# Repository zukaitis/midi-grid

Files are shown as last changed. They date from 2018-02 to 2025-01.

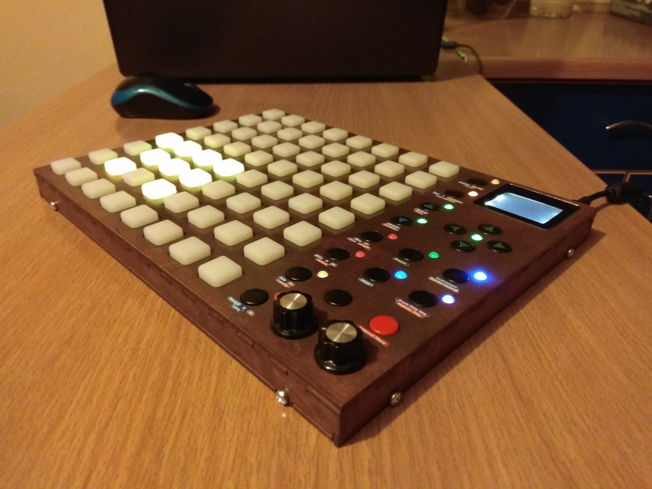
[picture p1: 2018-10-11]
Images/live_photo_8.jpg

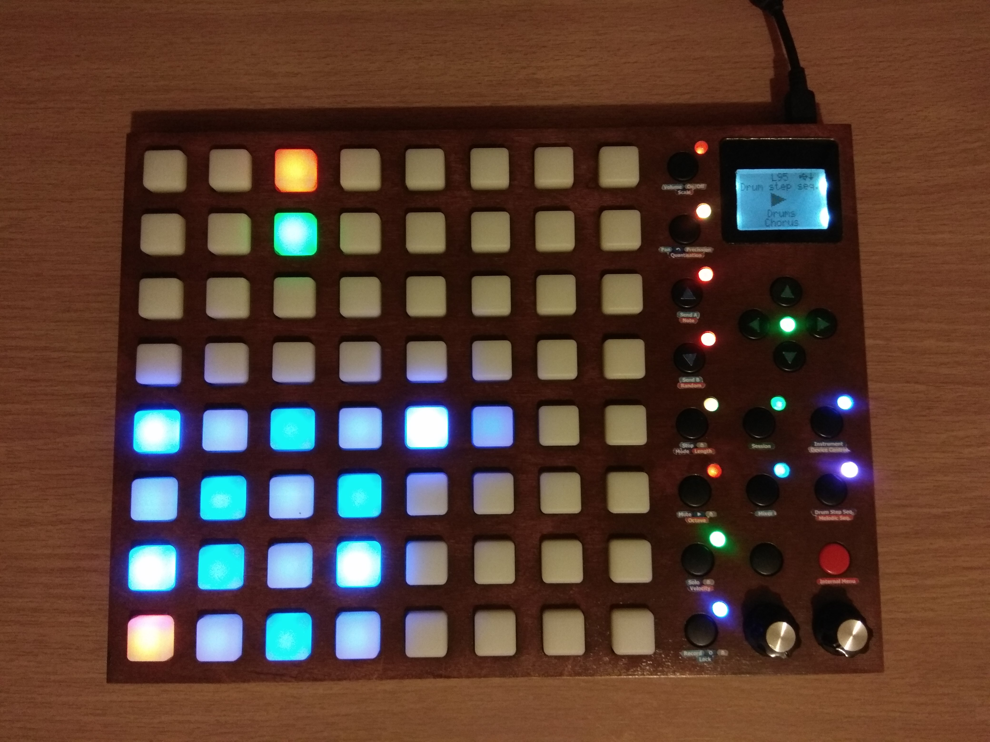
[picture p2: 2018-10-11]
Images/live_photo_12.jpg

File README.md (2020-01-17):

   

# midi-grid
DIY RGB MIDI grid controller

Video (https://youtu.be/mxI5Q21d1T0 "Demo video")

midi-grid is an open source MIDI controller, main part of which is 8x8 LED illuminated button grid.

Main features of the device:
- 8x8 RGB LED illuminated button matrix
- 17 additional MIDI control buttons, most of them paired with RGB LED indicator
- 1 internal menu button
- 2 rotary encoders, acting as MIDI controls
- Monochrome LCD display with adjustable backlight
- Physical MIDI input and output ports

Currently device is developed to work with [Ableton Live](https://www.ableton.com/en/live/),
specifically with modified [Launchpad95](http://motscousus.com/stuff/2011-07_Novation_Launchpad_Ableton_Live_Scripts/)
MIDI remote script - [Launchpad95g](https://github.com/zukaitis/Launchpad95g). Additional functionality, like stand-alone modes,
or compatibility with other DAWs may be implemented later.

More thorough information, regarding design and implementation, is available in [wiki of this project](https://github.com/zukaitis/midi-grid/wiki).

**This repository uses submodules -** [here's info how to fully clone it](https://stackoverflow.com/questions/3796927/how-to-git-clone-including-submodules)

## Thanks to
- [@mimuz](https://github.com/mimuz) - for sharing [STM32 USB MIDI library](https://github.com/mimuz/mimuz-tuch)
- [@pidcodes](https://github.com/pidcodes) - for providing USB VID/PID pair for this application
- [@hdavid](https://github.com/hdavid) - for making an amazing Ableton Live extension - [Launchpad95](https://github.com/hdavid/Launchpad95)
- [@michaelbecker](https://github.com/michaelbecker) - for making [FreeRTOS C++ wrappers](https://michaelbecker.github.io/freertos-addons)

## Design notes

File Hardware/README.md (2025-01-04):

# Bill of Materials

| Reference | Quantity | Part number | Description | Catalog link
| --- | --- | --- | --- | ---
| A1 | 1 | Nokia 5110 LCD | LCD module, ILI9341 controller, TFT LCD Display, 9-pin breakout PCB, SPI interface, 5V/3.3V | https://www.ebay.com/itm/84-48-LCD-Module-White-Backlight-Adapter-PCB-for-Nokia-5110-Arduino/400488314619
| C3, C2, C1, C6, C7, C8, C9, C11, C13, C17 | 10 |  | Capacitor MLCC, 100nF +/-10%, 6.3V, 0603, X5R | 
| C12, C10, C4, C5 | 4 |  | Capacitor MLCC, 2.2uF +/-10%, 6.3V, 0603, X5R | 
| C14, C15 | 2 |  | Capacitor MLCC, 27pF +/-10%, 6.3V, 0603, C0G | 
| C16, C18, C19, C21, C20 | 5 |  | Capacitor MLCC, 10uF +/-10%, 6.3V, 1206, X5R | 
| D1, D3, D5, D7, D9, D11, D13, D15, D17, D19, D21, D23, D25, D27, D29, D31, D33, D35, D37, D39, D41, D43, D45, D47, D49, D51, D53, D55, D57, D59, D61, D63, D65, D67, D69, D71, D73, D75, D77, D79, D81, D83, D85, D87, D89, D91, D93, D95, D97, D99, D101, D103, D105, D107, D109, D111, D113, D115, D117, D119, D121, D123, D125, D127, D129, D132, D136, D140, D142, D148, D150, D156, D134, D144, D152, D146, D154 | 77 |  | RGB LED, TH, d=5mm, p=1.27mm, common anode, diffused, pinout: RAGB | https://www.ebay.com/itm/100pcs-x-5mm-RGB-LED-Common-Cathode-Tri-Color-Emitting-Diodes-Diffused/291498456335
| D2, D4, D6, D8, D10, D12, D14, D16, D18, D20, D22, D24, D26, D28, D30, D32, D34, D36, D38, D40, D42, D44, D46, D48, D50, D52, D54, D56, D58, D60, D62, D64, D66, D68, D70, D72, D74, D76, D78, D80, D82, D84, D86, D88, D90, D92, D94, D96, D98, D100, D102, D104, D106, D108, D110, D112, D114, D116, D118, D120, D122, D124, D126, D128, D130, D133, D137, D141, D143, D149, D151, D157, D131, D135, D138, D139, D145, D153, D147, D155, D158 | 81 | LL4148-GS08 | 100V 0.3A standard switching diode, MiniMELF | https://www.tme.eu/en/details/ll4148-gs08/smd-universal-diodes/vishay/
| F1 | 1 | 1206L050YR | Polyfuse, 6V, 500mA, 1206 | https://eu.mouser.com/productdetail/?qs=PWhpLWeW8wckT8hV5jLiAA%3D%3D
| J1 | 1 | 105017-0001 | Connector, Micro USB | https://www.lemona.lt/?page=item&i_id=216110
| J2, J3 | 2 | FC68133 | 3-pin audio jack receptable (stereo/TRS connector) with 2 switching contacts | http://lt.farnell.com/cliff-electronic-components/fc68133/stereo-jack-3-5mm-5pos-pcb/dp/2518190
| J4 | 1 | 22-27-2041 | Generic connector, single row, 01x04 | 
| Q2, Q1, Q4, Q3, Q6, Q5, Q8, Q7, Q10, Q9, Q12, Q11, Q14, Q13, Q16, Q15, Q18, Q17, Q20, Q19 | 20 | BSH205G2 | MOSFET, P Channel, -2 A, -20 V, SOT-23 | http://uk.farnell.com/nexperia/bsh205g2/mosfet-p-ch-20v-2a-to236ab/dp/2498570
| Q28, Q27, Q26, Q25, Q32, Q31, Q30, Q29, Q24, Q23, Q22, Q21, Q33, Q34 | 14 | NX7002AK | MOSFET, N-Channel, 190 mA, 60 V, SOT-23 | http://uk.farnell.com/nexperia/nx7002ak/mosfet-single-n-ch-60v-0-19a-sot23/dp/2191746
| R21, R22, R23, R24, R64 | 5 |  | Resistor, 1K +/-5%, 0603 | 
| R28, R27, R26, R25 | 4 |  | Resistor, 249R +/-1%, 1206 | 
| R36, R35, R34, R33 | 4 |  | Resistor, 294R +/-1%, 1206 | 
| R44, R43, R42, R41 | 4 |  | Resistor, 51R +/-1%, 1206 | 
| R40, R39, R38, R37, R48, R47, R46, R45, R32, R31, R30, R29, R1, R2, R3, R4, R5, R6, R7, R8, R9, R10, R11, R12, R13, R14, R15, R16, R17, R18, R19, R20, R52, R51, R50, R49, R53, R54, R55, R59, R56, R63 | 42 |  | Resistor, 10K +/-5% 0603 | 
| R57, R58, R61, R60, R62 | 5 |  | Resistor, 220R +/-5%, 0603 | 
| R65 | 1 |  | Resistor, 1.6K +/-5%, 0603 | 
| SW1, SW2, SW3, SW4 | 4 |  | 4 x 4 silicone push button matrix, button size: 15mm x 15mm, matrix size 100mm x 100mm | http://www.better-silicone.com/Translucent-Silicone-Rubber-Button-Pad-4x4-Keyboard-pd847135.html
| SW5, SW6, SW7, SW8, SW9, SW10, SW11, SW12, SW13, SW14, SW15, SW16, SW17, SW18, SW19, SW20, SW23, SW24 | 18 |  | Tactile switch with stem for cap, 12mm x 12mm, h=7.3mm | https://www.ebay.com/itm/25PCS-12x12x7-3mm-Tact-Tactile-Push-Button-Momentary-SMD-PCB-Switch-with-Cap/382202288162
|  | 17 |  | Button cap, round, d=12mm, black | 
|  | 1 |  | Button cap, round, d=12mm, red | 
| SW21, SW22 | 2 |  | Tactile switch, 6mm x 6mm, h=4.3mm | 
| SW25, SW26 | 2 | EC12E24204A9 | Rotary encoder, incremental, 24 pulses/revolution | 
| U1 | 1 | STM32F413RHT6 | Microcontroller, ARM Cortex-M4, LQFP64, Flash: 1536KB Ram: 320KB,100MHz Voltage: 1.7..3.6V IO-pins: 50 | 
| U4, U3, U2 | 3 | SN74HC138PW | Decoder 3 to 8 (active low outputs), TSSOP-16 | http://uk.farnell.com/texas-instruments/sn74hc138pw/ic-decoder-demux-smd/dp/9591095
| U5 | 1 | USBUF02W6 | 2-line EMI filter and ESD protection with R pull-up, for USB interfaces, SOT-363 | http://uk.farnell.com/stmicroelectronics/usbuf02w6/filter-low-pass-1ghz-sot-323-6/dp/2341659
| U6 | 1 | VO617A | Optocoupler, SO-4 | https://eu.mouser.com/ProductDetail/Vishay-Semiconductors/VO617A-8X017T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
| U7 | 1 | LD1117STR | 800mA Low-Dropout Linear Regulator, adjustable output, SOT-223 | http://uk.farnell.com/stmicroelectronics/ld1117str/ic-v-reg-adj-1-25-15v-smd-1117/dp/1202824
| Y1 | 1 | ABM3B-8.000MHZ-B2-T | Crystal 8.0MHz 18pf 20ppm -20C +70C | https://eu.mouser.com/ProductDetail/?qs=NE97hfUNX0Ef9OqIOqO2cA%3D%3D
|  | 71 |  | Standoff, M2 * 5mm | https://www.ebay.com/itm/KNURLED-BRASS-SPACER-FEMALE-FEMALE-SCREW-PC-MOTHERBOARD-STANDOFF-M2-X-3MM-25MM-/122039617381
|  | 64 |  | Phillips screw, round head, M2 * 6mm | https://www.ebay.com/itm/M2-A2-304-Stainless-Steel-Phillips-Round-Head-Pan-Head-Screws-Bolts-M2-3-M2-60-/122691038427
|  | 23 |  | Phillips screw, flat head, M2 * 5mm | https://www.ebay.com/itm/M2-A2-304-Stainless-Steel-Phillips-Flat-Head-Screws-Bolts-M2-3mm-M2-60mm-/122689688965

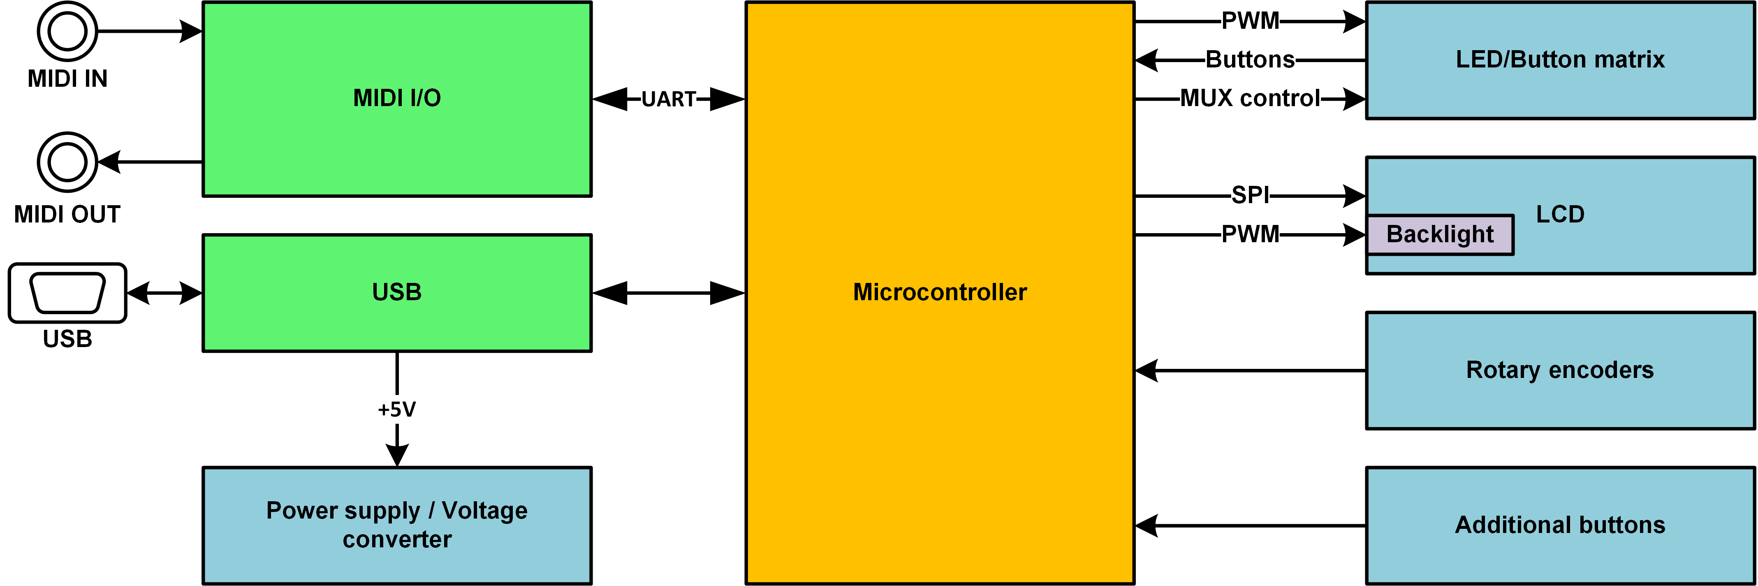
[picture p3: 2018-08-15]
Images/hardware_block_diagram.png

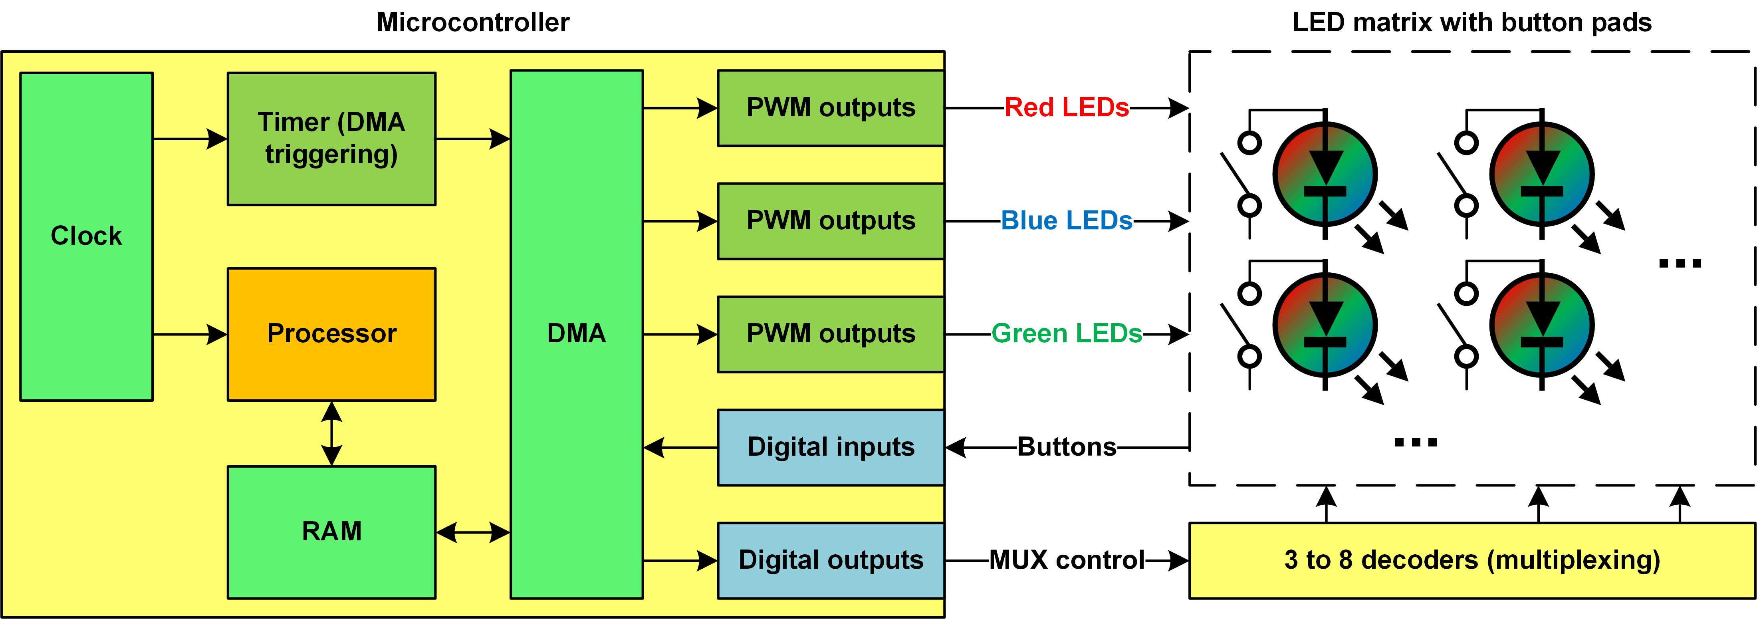
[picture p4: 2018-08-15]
Images/matrix_control_diagram.png

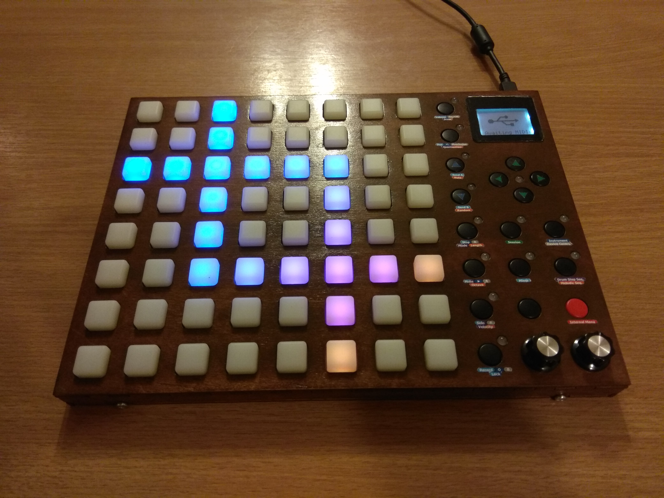
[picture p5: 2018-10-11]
Images/live_photo_1.jpg

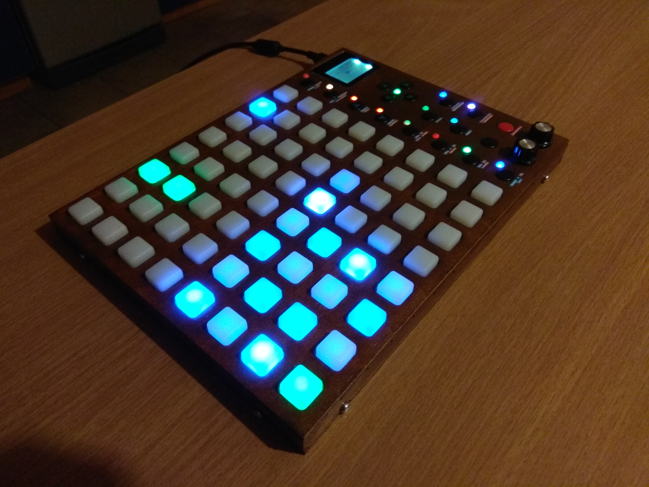
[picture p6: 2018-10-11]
Images/live_photo_4.jpg

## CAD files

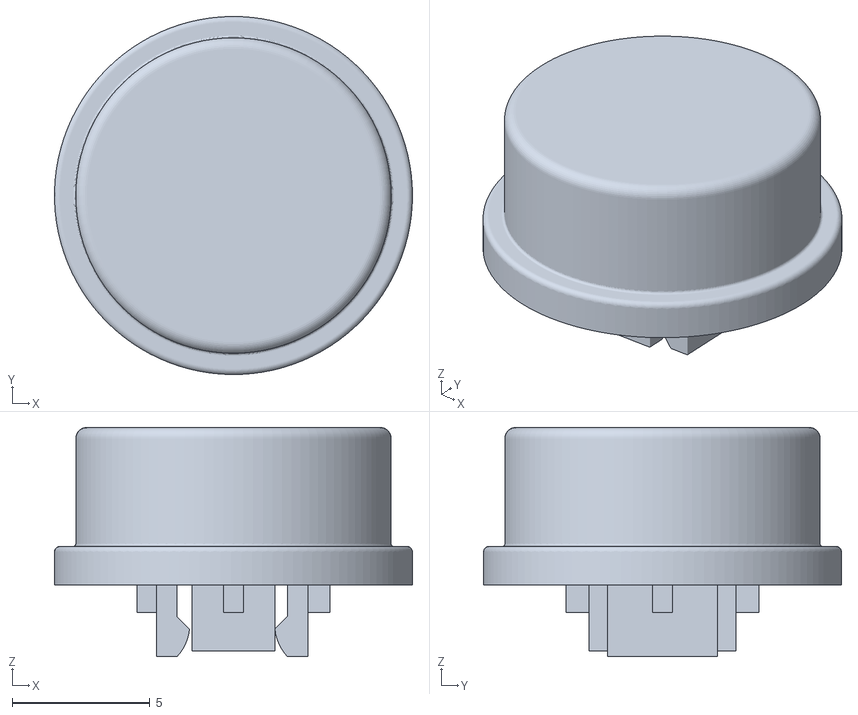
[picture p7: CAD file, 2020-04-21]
Case/models/adafruit_round_button_cap_1009.stl
13.0 x 13.0 x 8.32

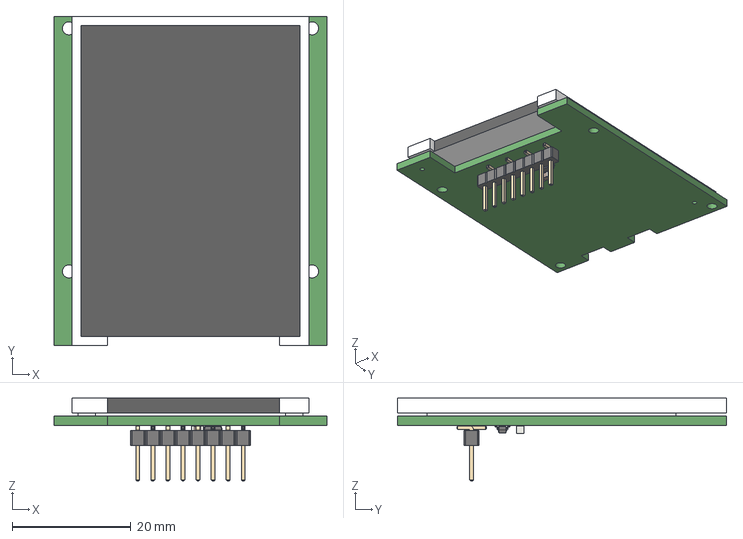
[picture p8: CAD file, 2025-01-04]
Hardware/lcd_board/lcd_board.step
46.0 x 55.5 x 14.0 mm

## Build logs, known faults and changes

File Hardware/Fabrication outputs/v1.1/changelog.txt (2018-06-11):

v1.1 - not yet fabricated
Changes:
- switched microcontroller pins LCD_DC and LCD_CS, so that hardware chip select of microcontroller could be used
- connected LCD_LIGHT output to PB5 GPIO pin (used to be TP3)

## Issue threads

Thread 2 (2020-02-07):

Need help for pcb

4dvn, 2020-02-07:
Can you upload the gerber file, i need the instruction to compile the source, thank you!

zukaitis, 2020-02-07:
I uploaded Gerber files for newest version into Hardware/Fabrication outputs/v1.1 . Although, be aware, that these files haven't yet been used in production, so make sure to review them with Gerber viewer of your choice

Closed 2020-02-07.

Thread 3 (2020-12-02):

Need help to custom it

4dvn, 2020-12-02:
I have a 16 buttons midi from avr project and i wanna switch it to stm32, can you give me some example code of it with rgb?

zukaitis, 2020-12-02:
Hey, all the hardware configuration (GPIO, PWM, DMA) is set up in [GridDriver.cpp](https://github.com/zukaitis/midi-grid/blob/master/Firmware/src/hardware/grid/GridDriver.cpp) file. Since you only need 16 buttons, you could get away with using as little as 3 PWM GPIO outputs (instead of 12 used in my circuit), but that depends on the way you want to connect them, check the [schematics](https://github.com/zukaitis/midi-grid/blob/master/Hardware/midi_grid.pdf) for reference. Hope that helps, have fun with your project!

Closed 2020-12-09.

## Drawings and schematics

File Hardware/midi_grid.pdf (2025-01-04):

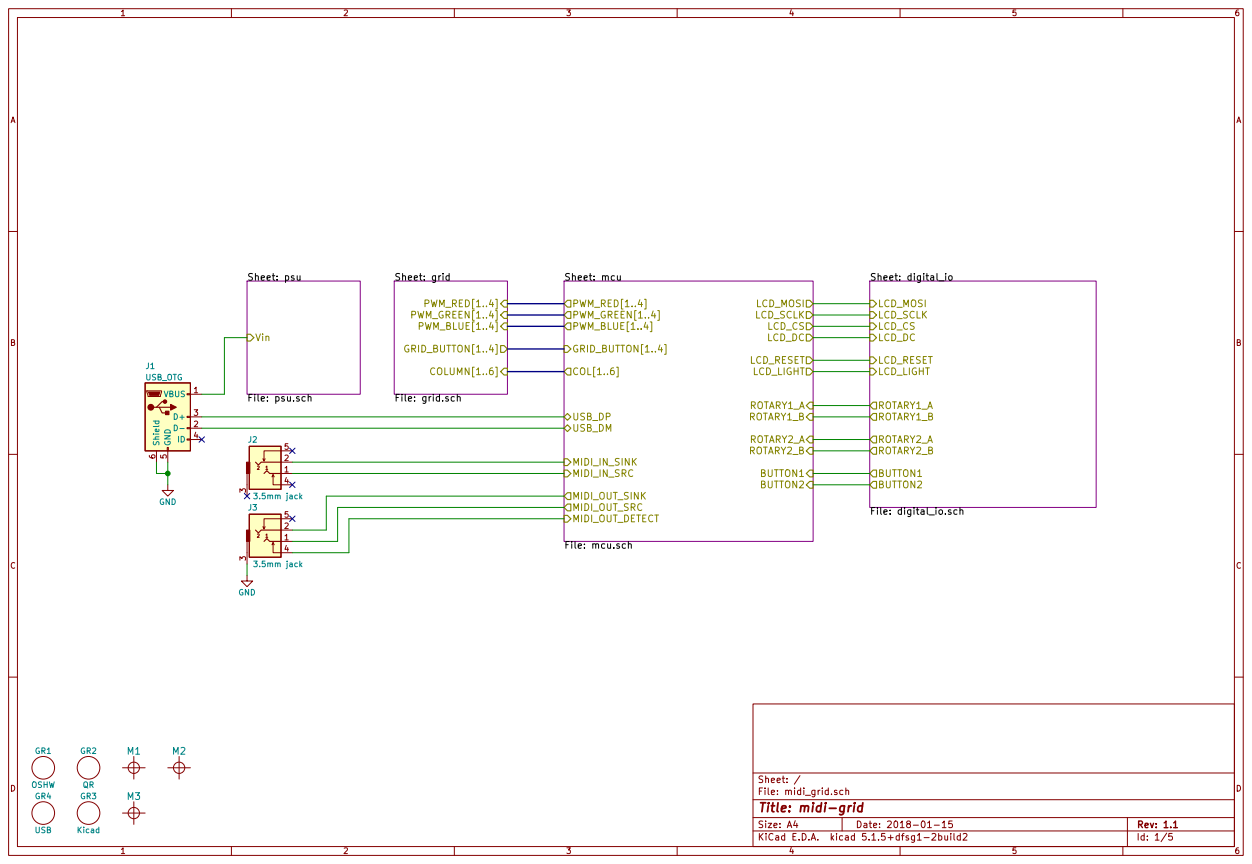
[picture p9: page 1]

Sheet: mcu File: mcu.sch PWM_RED[1..4]

File: midi_grid.sch Sheet: /
Id: 1/5 Title: midi-grid

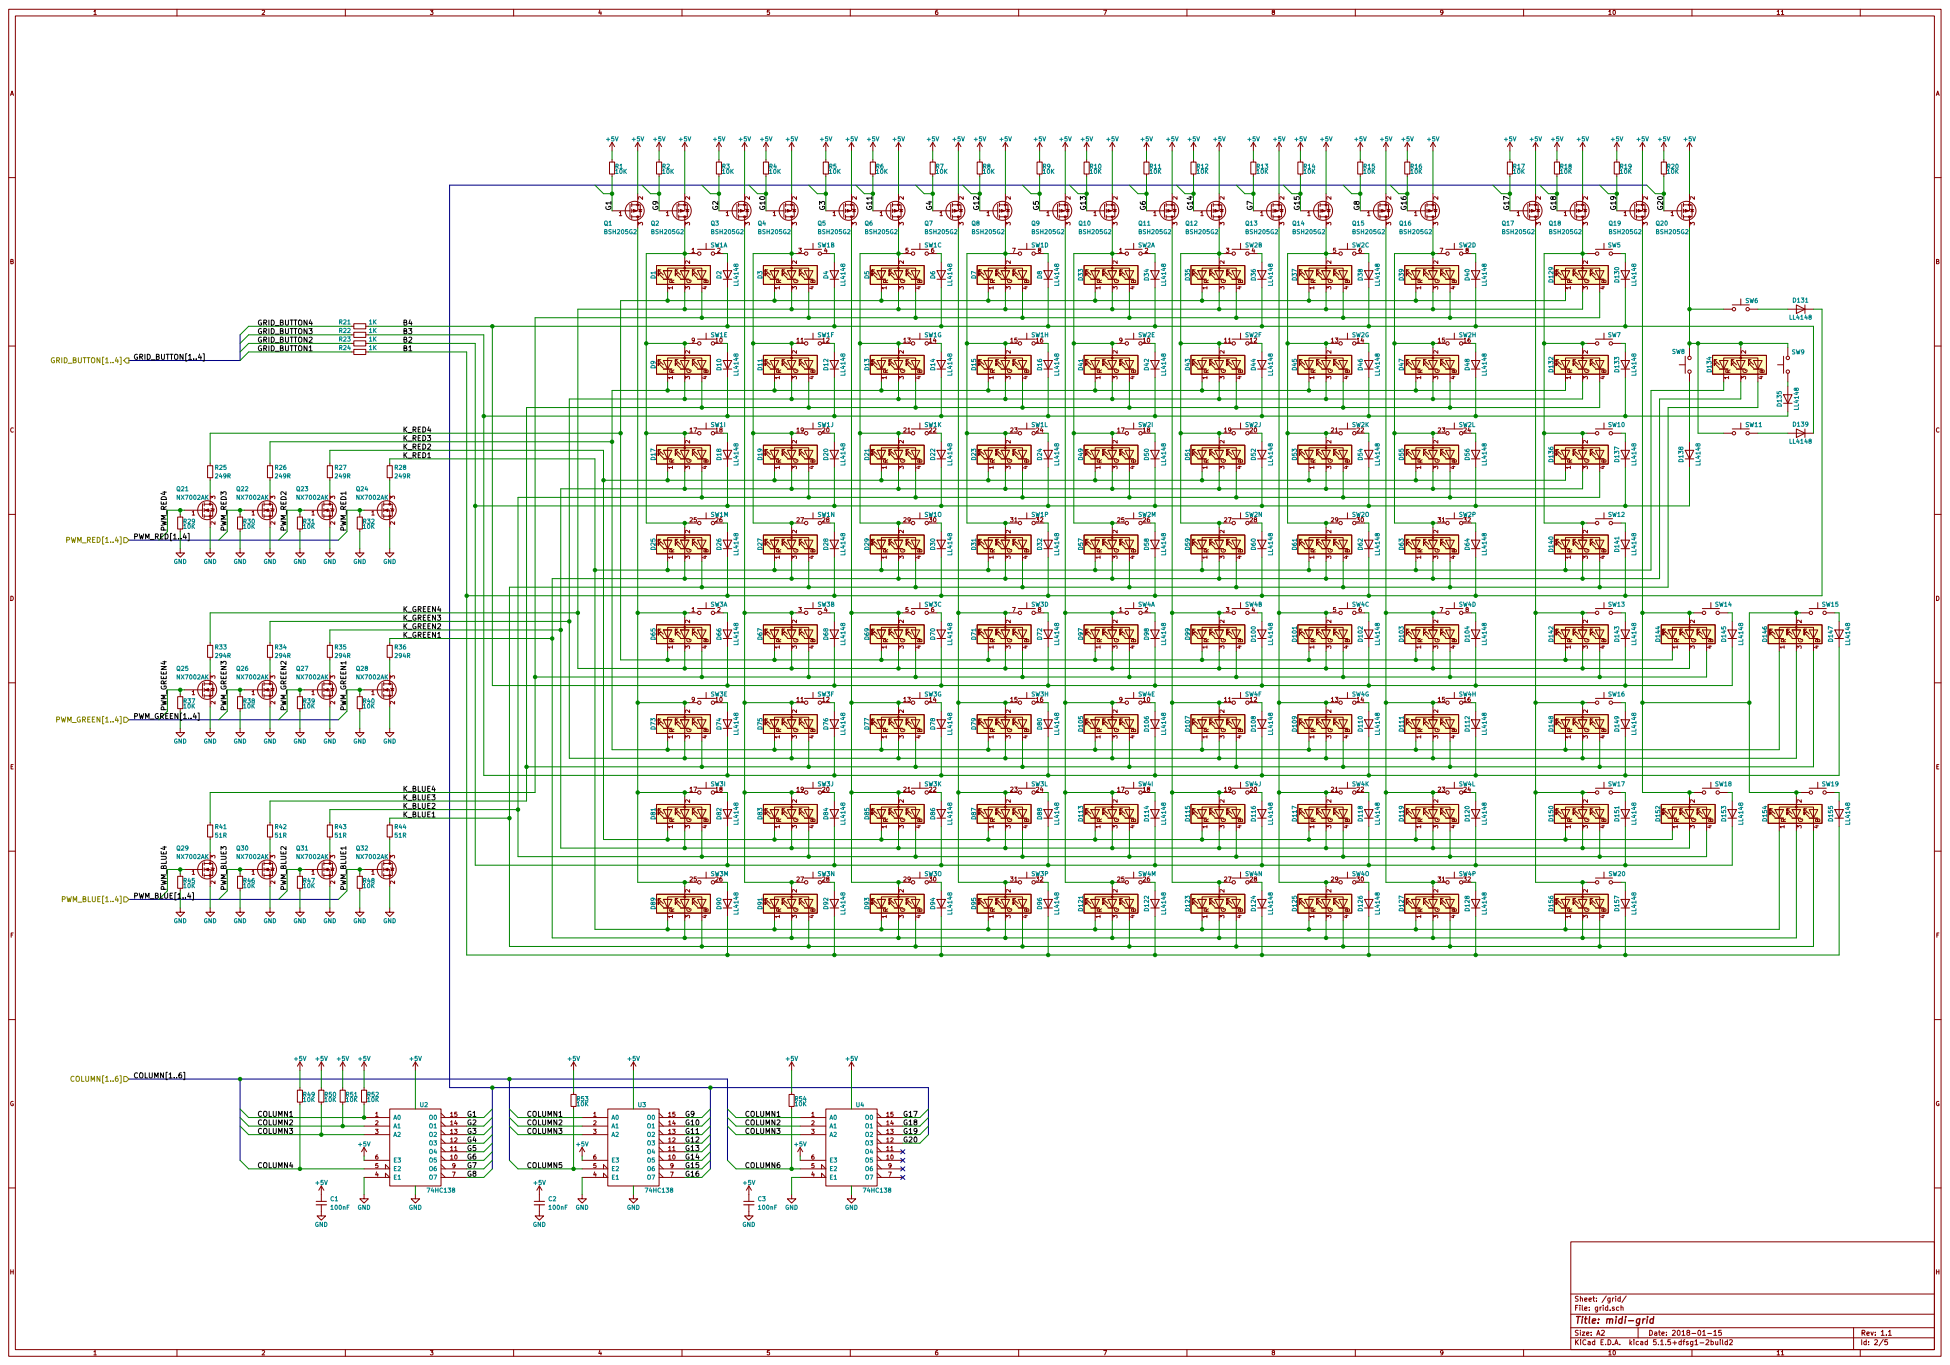
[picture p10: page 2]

Sheet: /grid/
File: grid.sch
Id: 2/5 Title: midi-grid

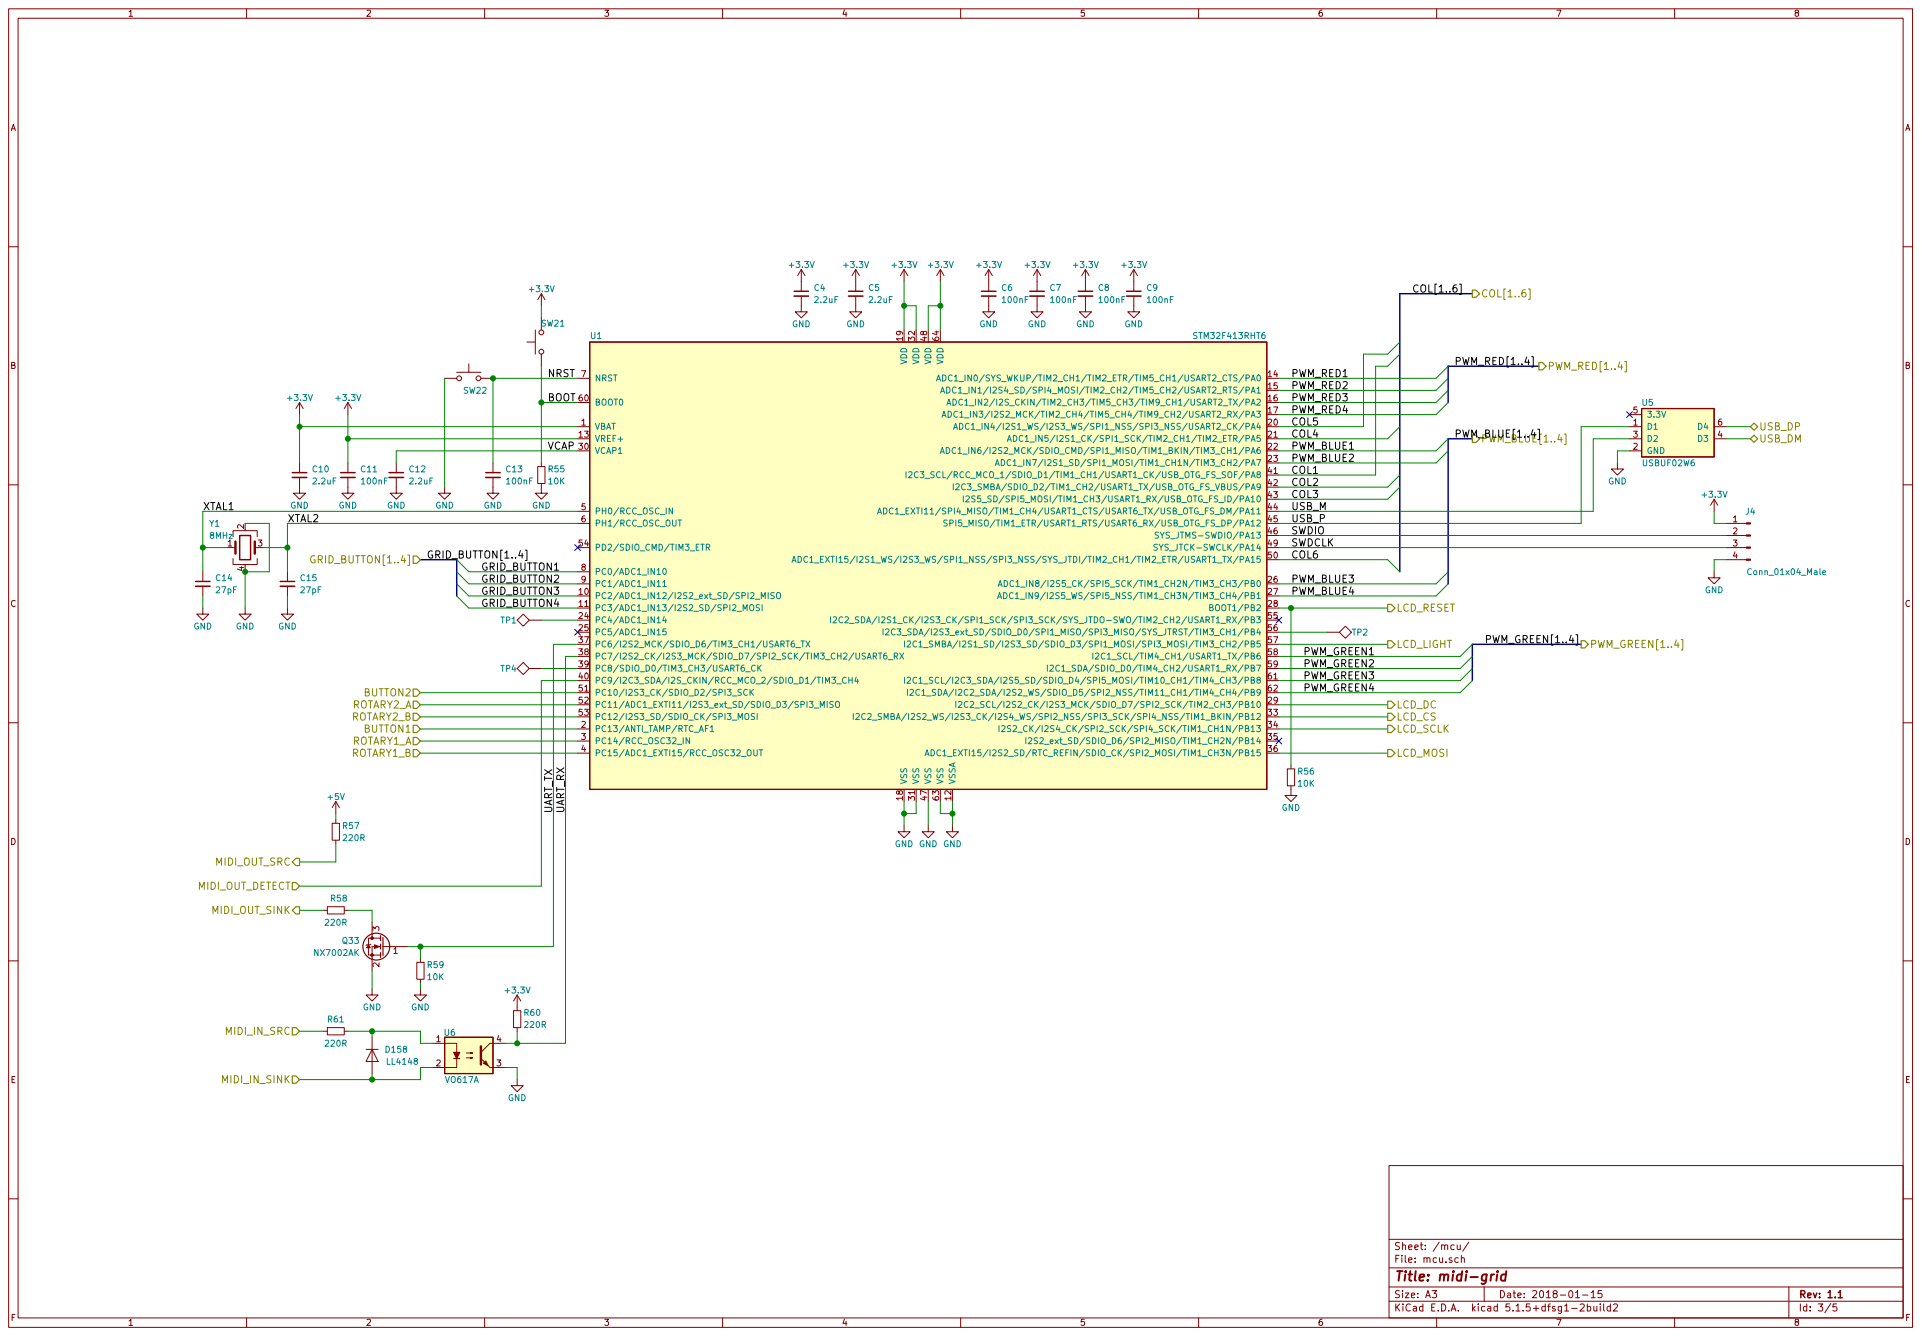
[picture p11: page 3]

BOOT | PWM_RED2

PWM_RED3
PWM_RED4
COL5

VCAP | PWM_BLUE1

PWM_BLUE2
COL1

USB_P
SWDIO SWDCLK COL6

PWM_GREEN1
PWM_GREEN2
PWM_GREEN3

File: mcu.sch Sheet: /mcu/
Id: 3/5 Title: midi-grid

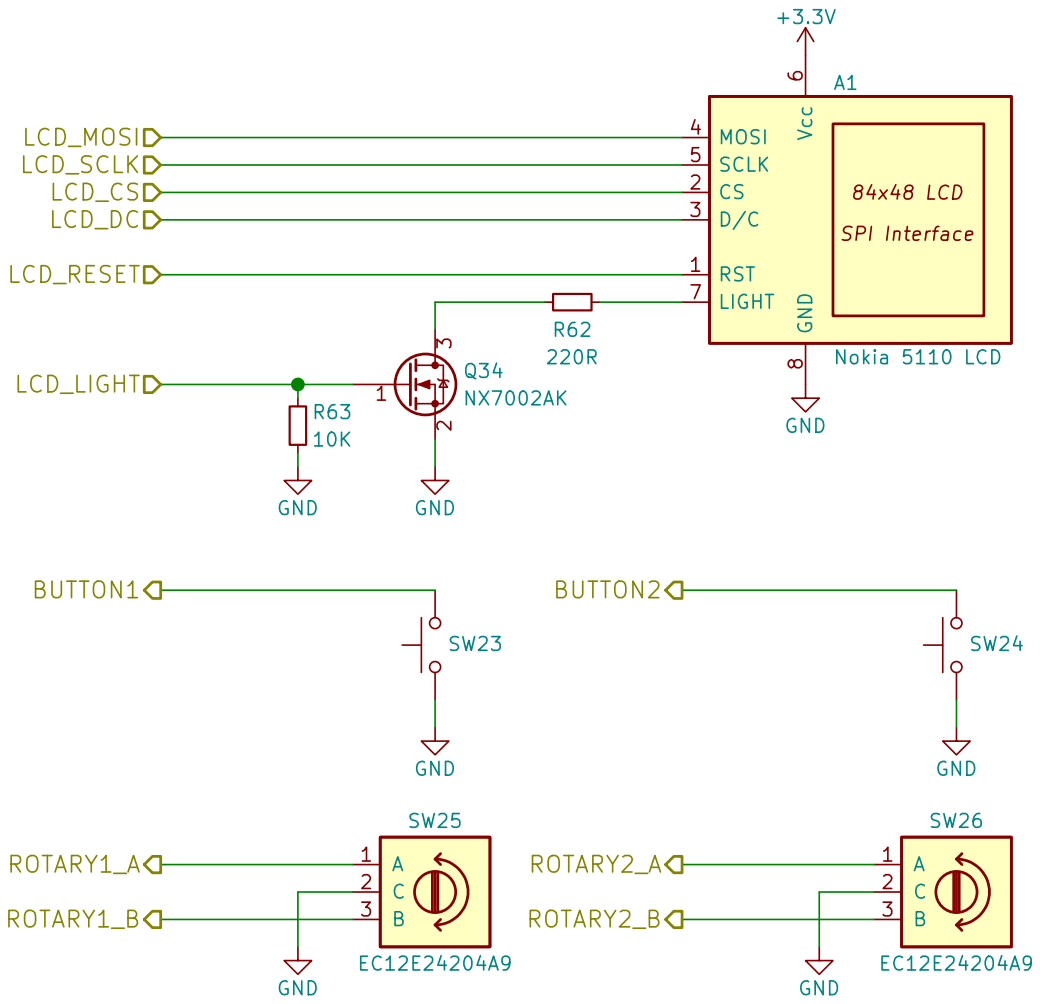
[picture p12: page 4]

File: digital_io.sch
Id: 4/5 Title: midi-grid

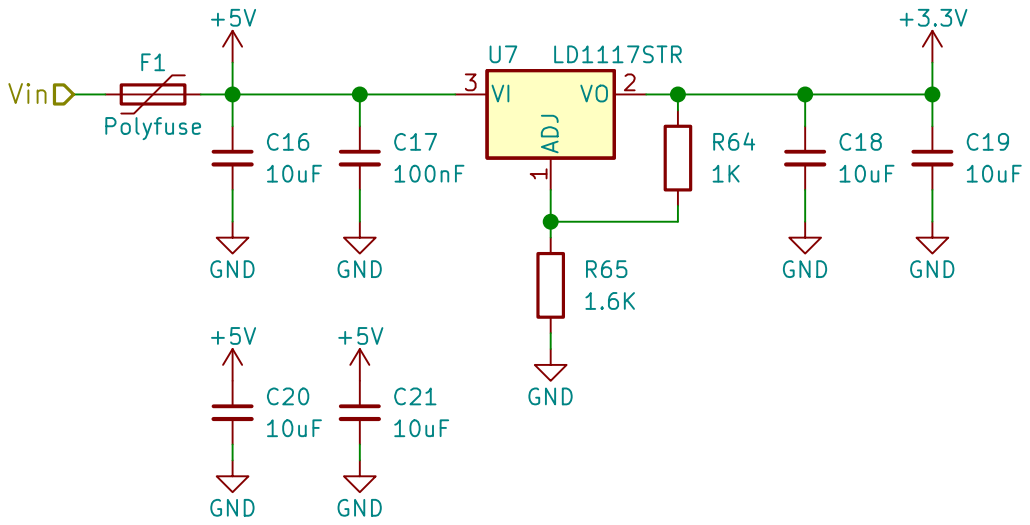
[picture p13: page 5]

Sheet: /psu/
File: psu.sch
Id: 5/5 Title: midi-grid

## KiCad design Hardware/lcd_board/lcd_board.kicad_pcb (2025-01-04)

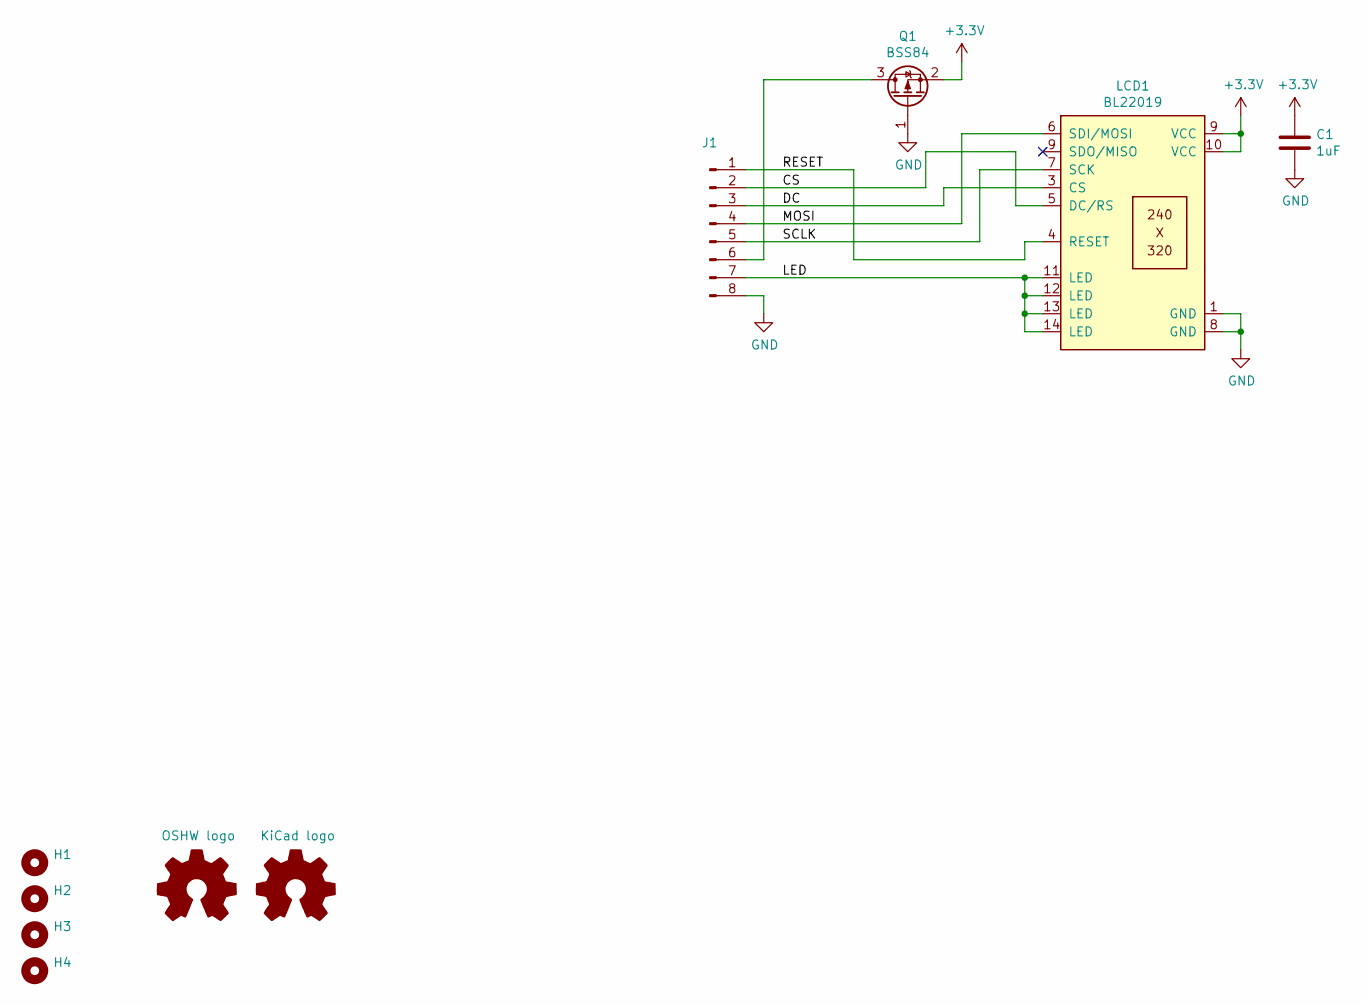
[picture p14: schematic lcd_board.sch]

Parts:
C1: 1uF; C_0805_2012Metric
H1, H2, H3, H4: MountingHole; MountingHole_2.2mm_M2
J1: Conn_01x08_Male; PinHeader_1x08_P2.54mm_Vertical_SMD_Pin1Left
LCD1: BL22019
LOGO1: OSHW logo; OSHW-Logo_11.4x12mm_Copper
LOGO2: KiCad logo; KiCad-Logo2_6mm_Copper
Q1: BSS84; SOT-23

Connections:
+3V3: C1.1, LCD1.9 (SDO/MISO), LCD1.10 (VCC), Q1.2 (S)
/CS: J1.2, LCD1.5 (DC/RS)
/DC: J1.3, LCD1.3 (CS)
/LED: J1.7, LCD1.11 (LED), LCD1.12 (LED), LCD1.13 (LED), LCD1.14 (LED)
/MOSI: J1.4, LCD1.6 (SDI/MOSI)
/RESET: J1.1, LCD1.4 (RESET)
/SCLK: J1.5, LCD1.7 (SCK)
GND: C1.2, J1.8, LCD1.1 (GND), LCD1.8 (GND), Q1.1 (G)
unnamed: J1.6, Q1.3 (D)

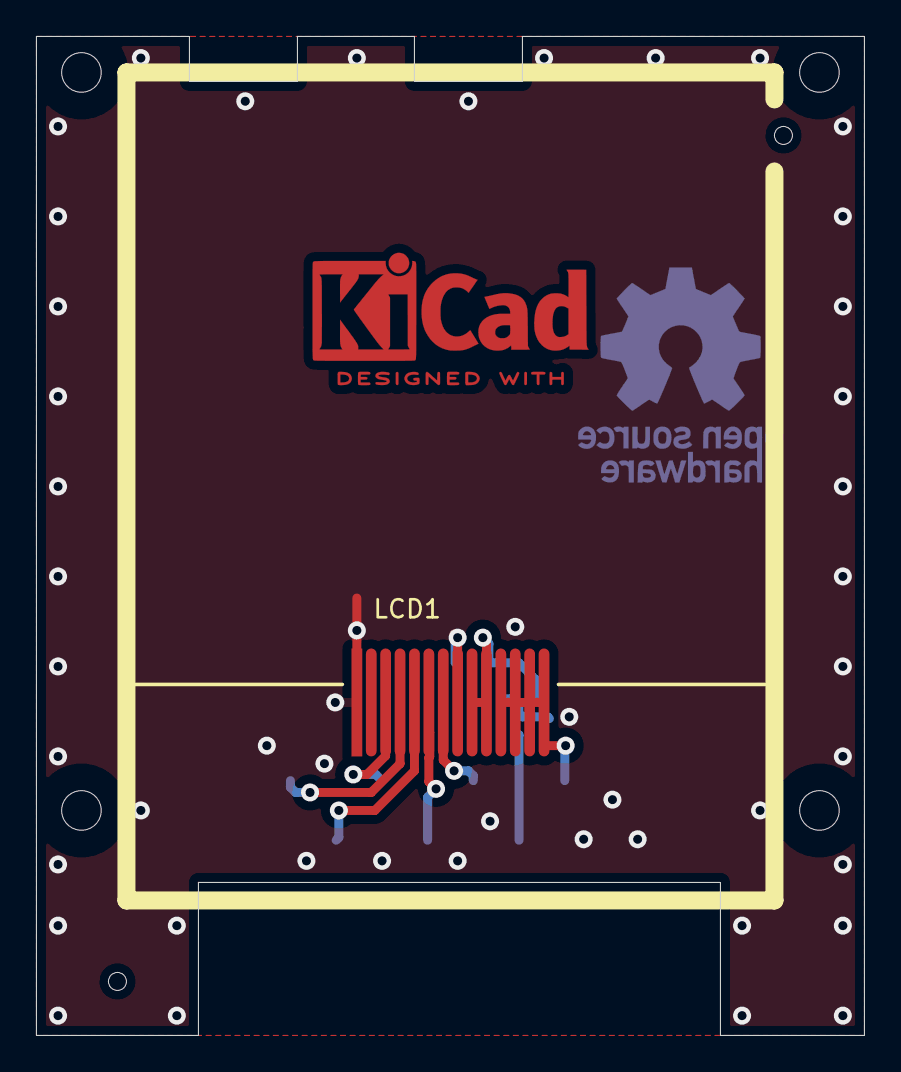
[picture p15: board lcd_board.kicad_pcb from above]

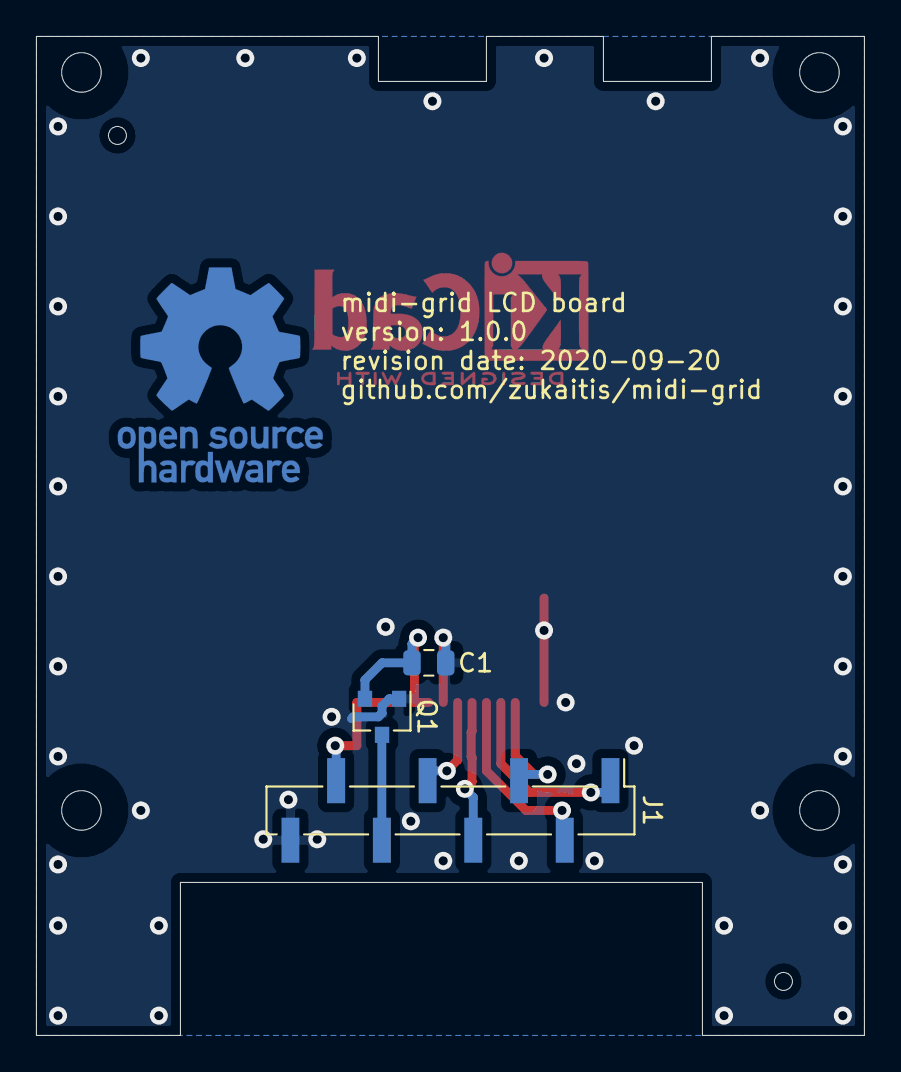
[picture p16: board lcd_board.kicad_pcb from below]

Board: 2 copper layers, 46.0 x 55.5 mm, 10 parts (4 on the bottom side), 9 nets.

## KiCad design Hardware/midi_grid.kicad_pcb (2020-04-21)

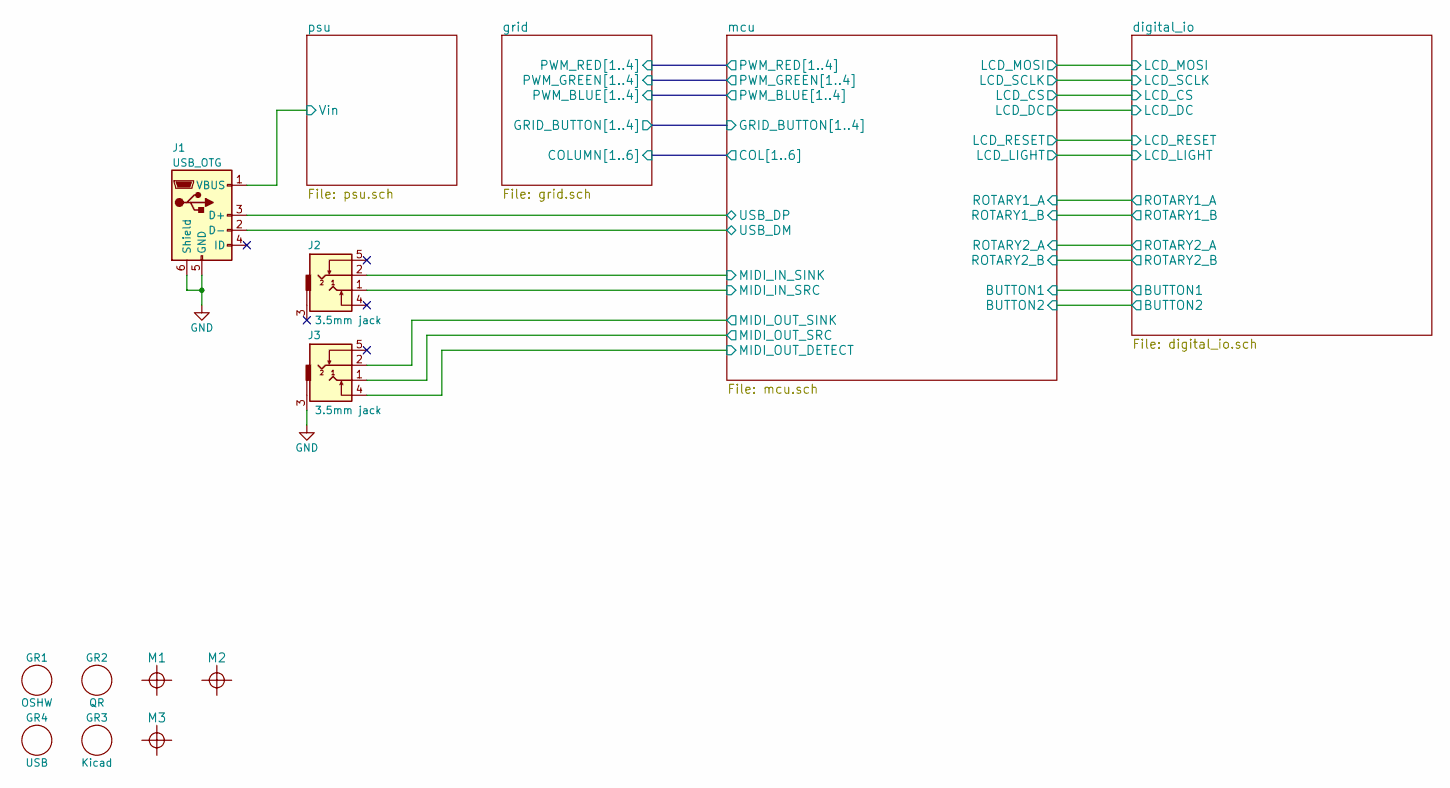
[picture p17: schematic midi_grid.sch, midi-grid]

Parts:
GR1: OSHW; Logo_OSHW
GR2: QR; qr_url
GR3: Kicad; Symbol_KiCAD-Logo_CopperAndSilkScreenTop
GR4: USB; usb_logo_6x3mm
J1: USB_OTG; USB_Micro-B_Molex-105017-0001
J2, J3: 3.5mm jack; 3.5mm-jack
M1, M2, M3: Mounting_hole; MountingHole_2.2mm_M2

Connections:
/mcu/MIDI_IN_SINK: J2.2; also elsewhere on the board
/mcu/MIDI_IN_SRC: J2.1; also elsewhere on the board
/mcu/MIDI_OUT_DETECT: J3.4; also elsewhere on the board
/mcu/MIDI_OUT_SINK: J3.2; also elsewhere on the board
/mcu/MIDI_OUT_SRC: J3.1; also elsewhere on the board
/mcu/USB_DM: J1.2 (D-); also elsewhere on the board
/mcu/USB_DP: J1.3 (D+); also elsewhere on the board
/psu/Vin: J1.1 (VBUS); also elsewhere on the board
GND: J1.5 (GND), J1.6 (Shield), J3.3; also elsewhere on the board

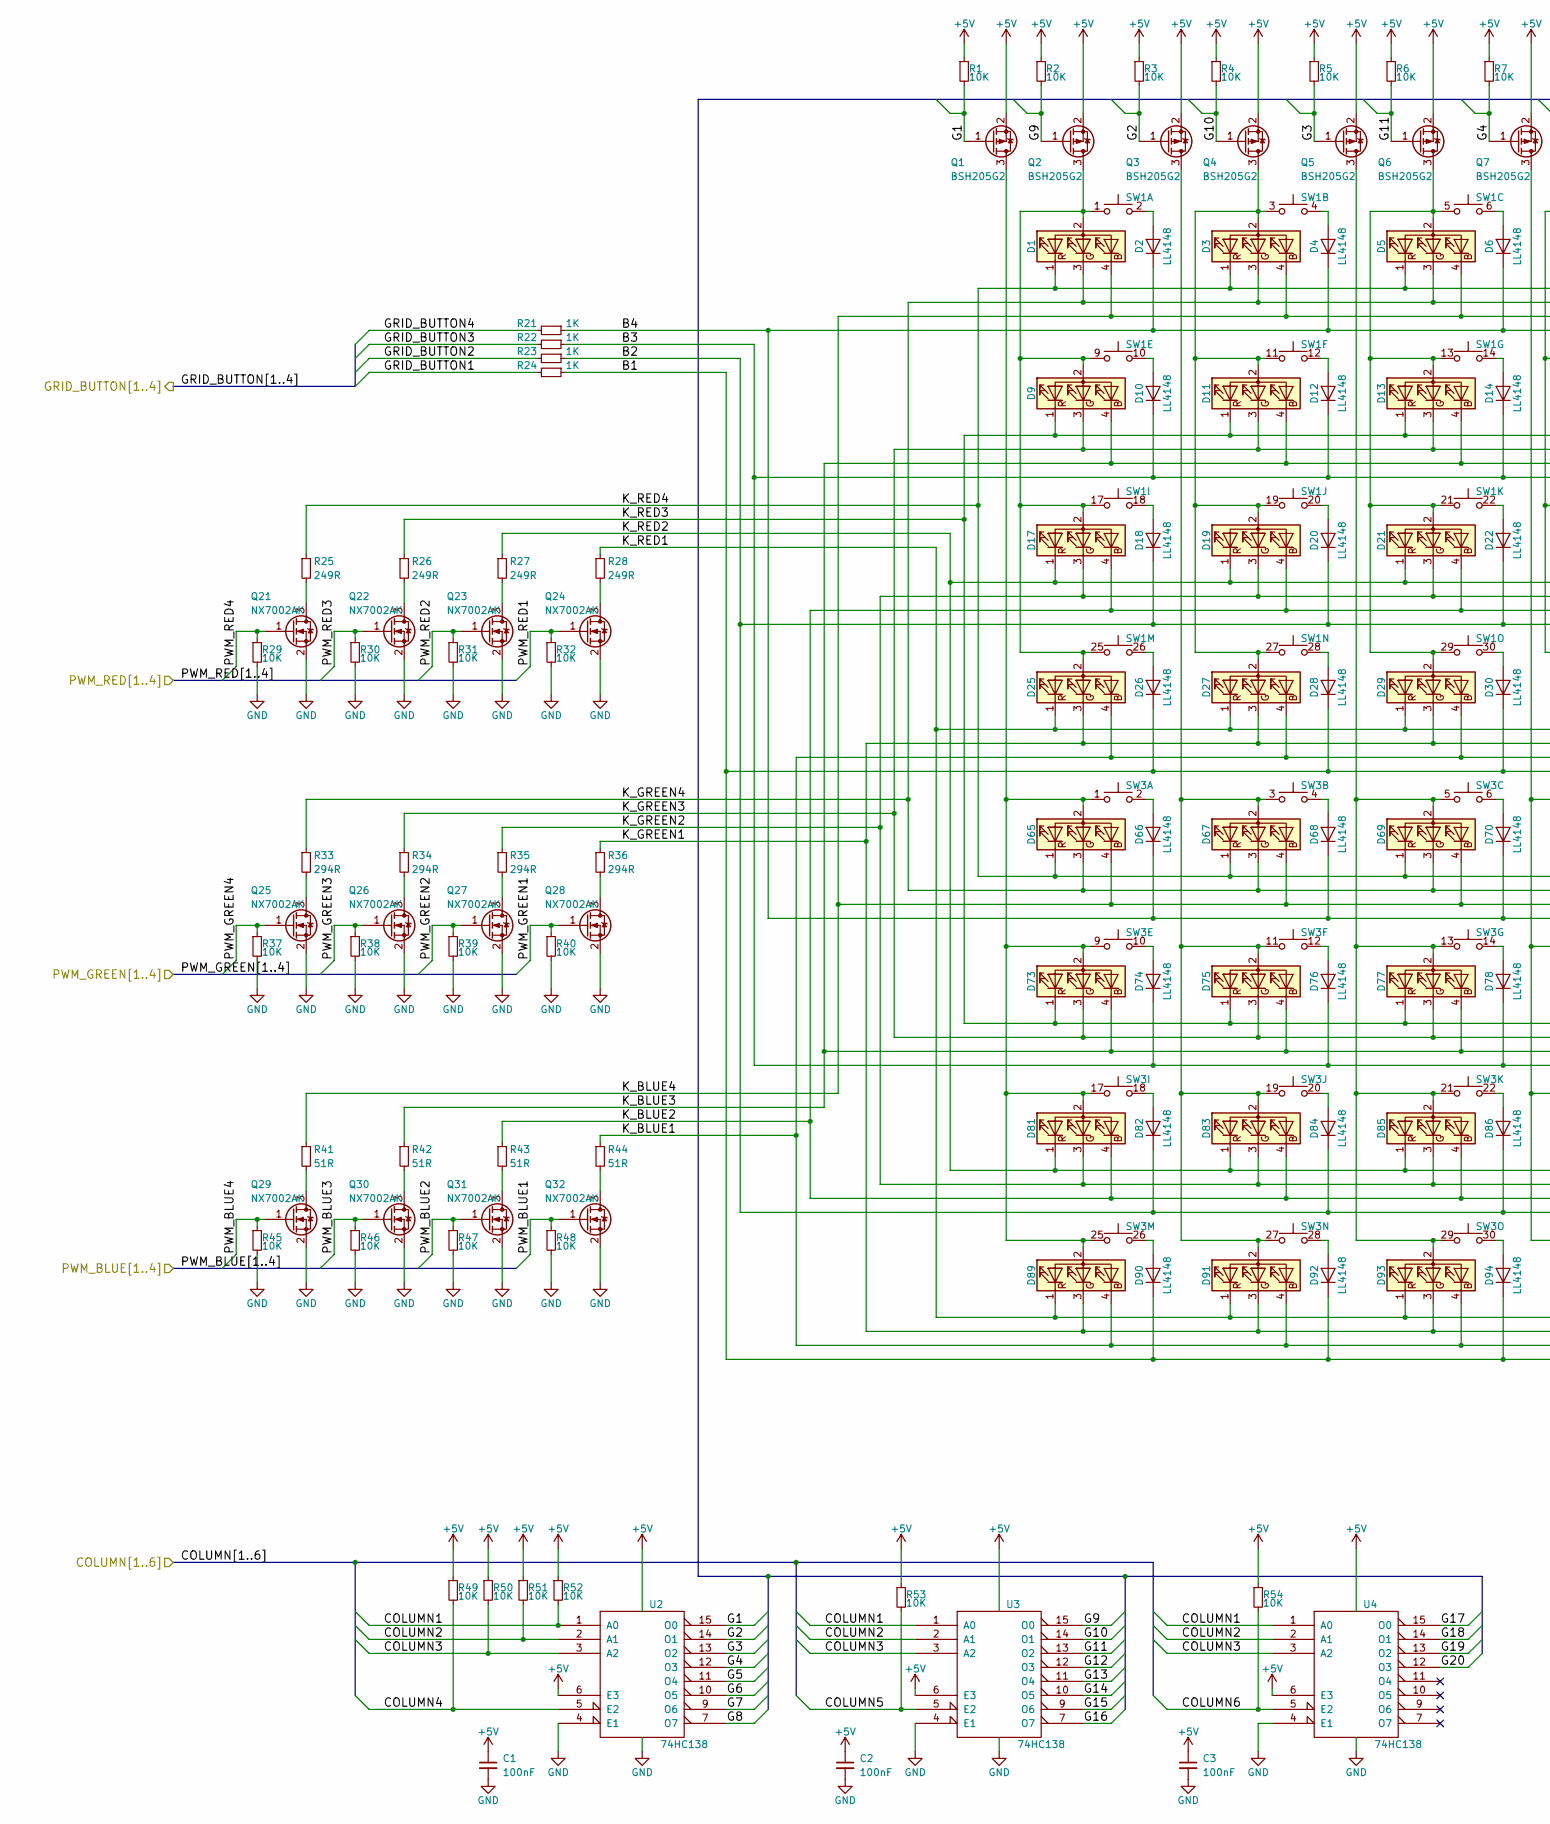
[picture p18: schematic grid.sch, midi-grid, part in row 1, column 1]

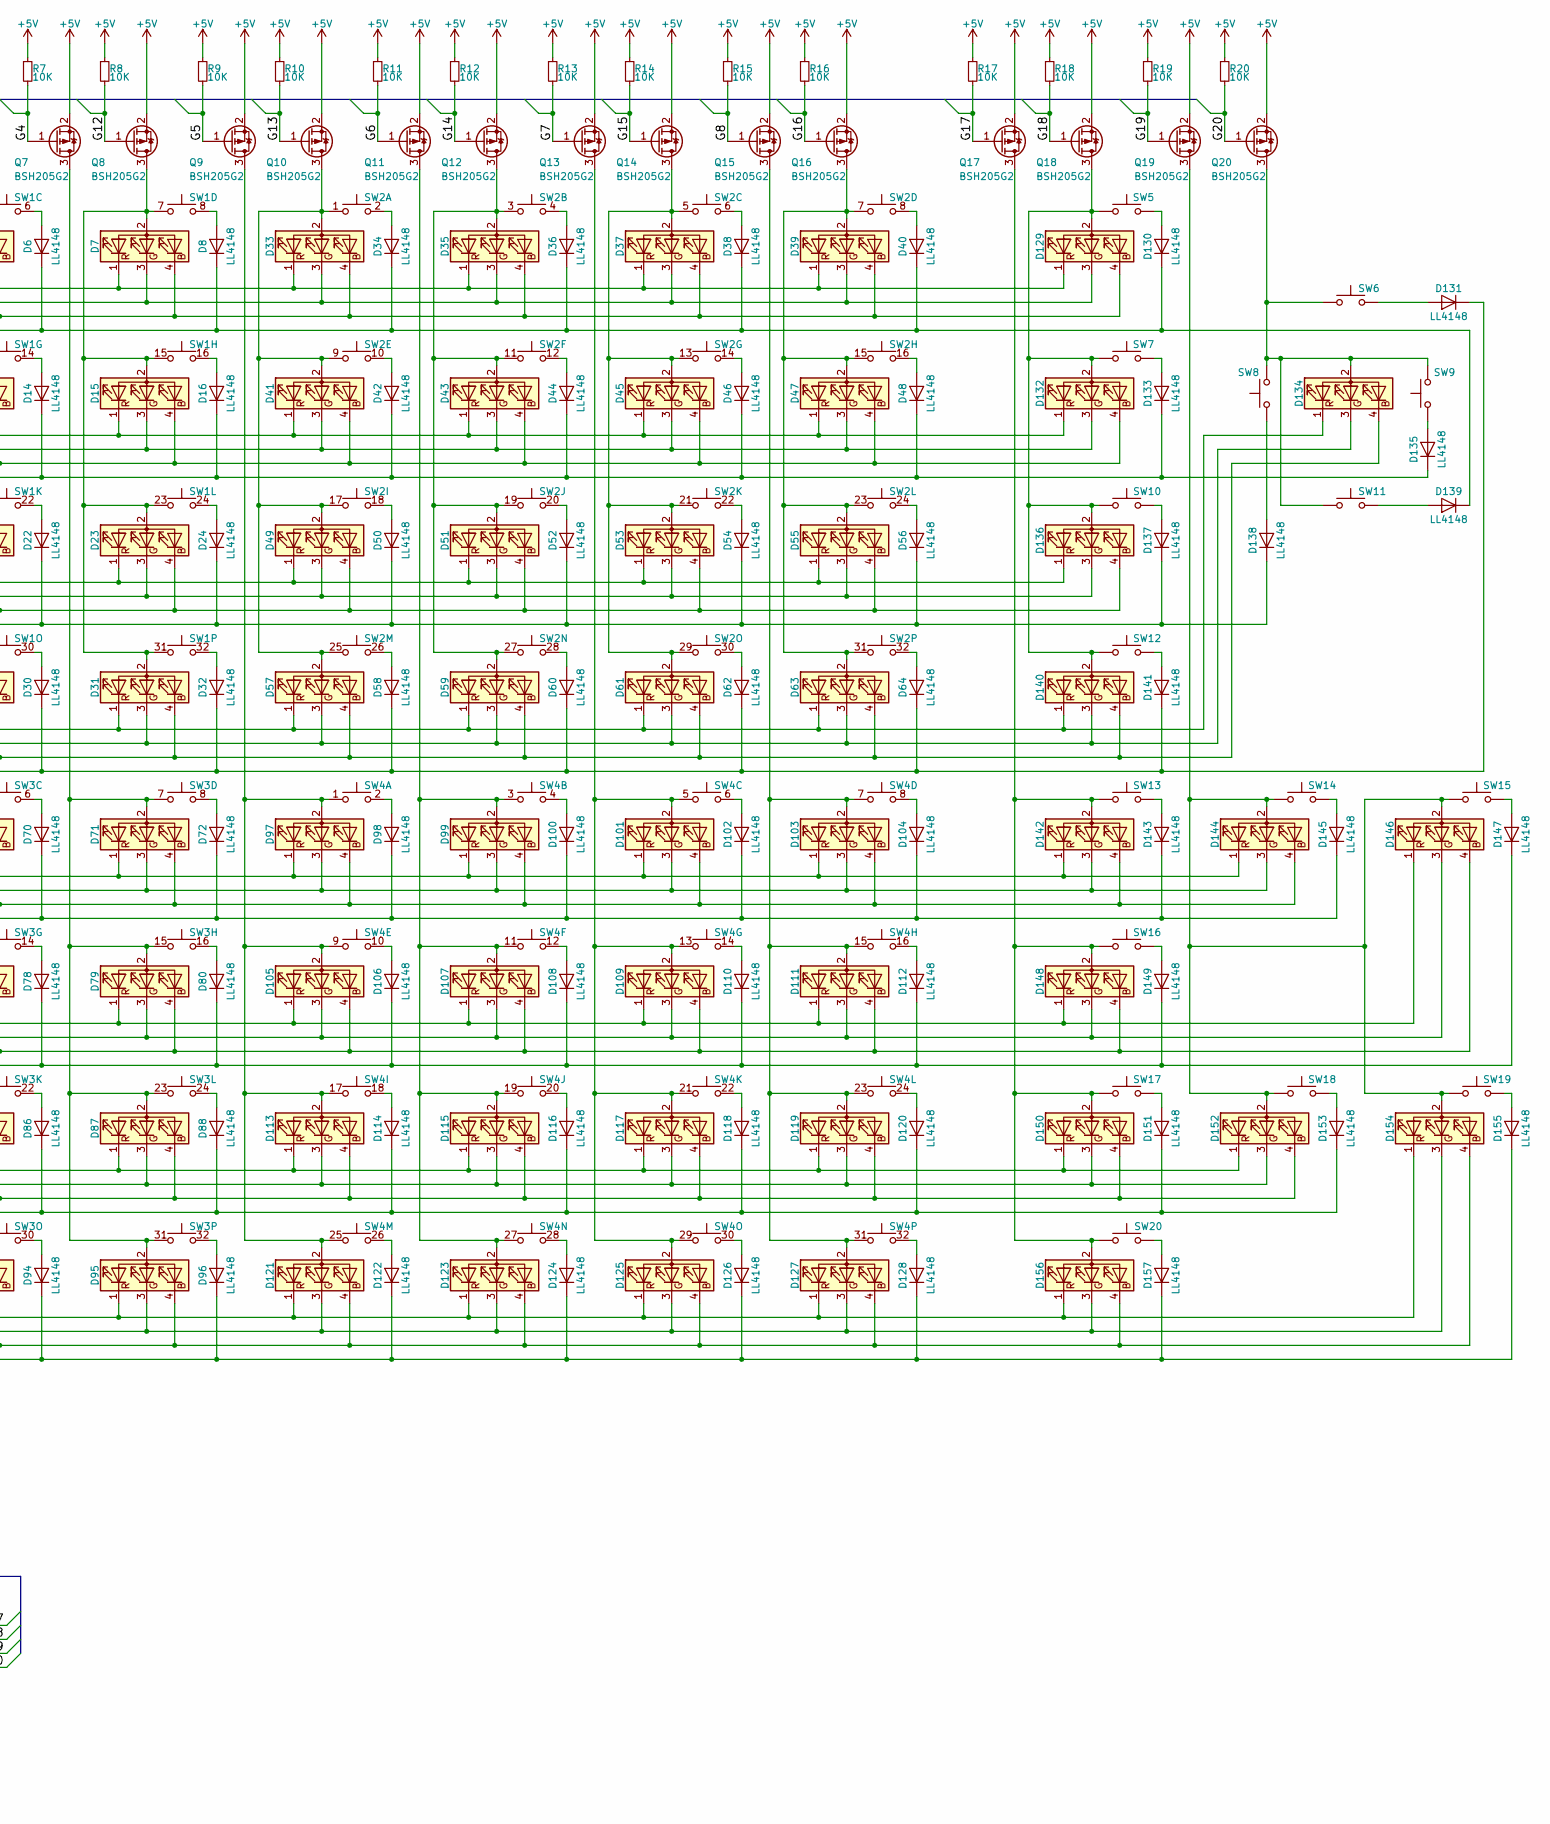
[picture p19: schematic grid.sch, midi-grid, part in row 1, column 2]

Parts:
C1, C2, C3: 100nF; C_0603
D1, D3, D5, D7, D9, D11, D13, D15, D17, D19, D21, D23, D25, D27, D29, D31, D33, D35, D37, D39, D41, D43, D45, D47, D49, D51, D53, D55, D57, D59, D61, D63, D65, D67, D69, D71, D73, D75, D77, D79, D81, D83, D85, D87, D89, D91, D93, D95, D97, D99, D101, D103, D105, D107, D109, D111, D113, D115, D117, D119, D121, D123, D125, D127: LED_RAGB; LED_D5.0mm-4
D2, D4, D6, D8, D10, D12, D14, D16, D18, D20, D22, D24, D26, D28, D30, D32, D34, D36, D38, D40, D42, D44, D46, D48, D50, D52, D54, D56, D58, D60, D62, D64, D66, D68, D70, D72, D74, D76, D78, D80, D82, D84, D86, D88, D90, D92, D94, D96, D98, D100, D102, D104, D106, D108, D110, D112, D114, D116, D118, D120, D122, D124, D126, D128, D130, D131, D133, D135, D137, D138, D139, D141, D143, D145, D147, D149, D151, D153, D155, D157: LL4148; D_MiniMELF
D129, D132, D134, D136, D140, D142, D144, D146, D148, D150, D152, D154, D156: LED_RAGB; LED_D5.0mm-4-4mm_standoff
Q1, Q2, Q3, Q4, Q5, Q6, Q7, Q8, Q9, Q10, Q11, Q12, Q13, Q14, Q15, Q16, Q17, Q18, Q19, Q20: BSH205G2; SOT-23
Q21, Q22, Q23, Q24, Q25, Q26, Q27, Q28, Q29, Q30, Q31, Q32: NX7002AK; SOT-23
R1, R2, R3, R4, R5, R6, R7, R8, R9, R10, R11, R12, R13, R14, R15, R16, R17, R18, R19, R20, R29, R30, R31, R32, R37, R38, R39, R40, R45, R46, R47, R48, R49, R50, R51, R52, R53, R54: 10K; R_0603
R21, R22, R23, R24: 1K; R_0603
R25, R26, R27, R28: 249R; R_1206
R33, R34, R35, R36: 294R; R_1206
R41, R42, R43, R44: 51R; R_1206
SW1, SW2, SW3, SW4: Button_matrix_4x4; 4x4_silicone_button_matrix
SW5, SW7, SW10, SW12, SW13, SW14, SW15, SW16, SW17, SW18, SW19, SW20: SW_Push; Tactile_switch_12x12
SW6, SW8, SW9, SW11: SW_Push; Tactile_switch_12x12_no_holes
U2, U3, U4: 74HC138; TSSOP-16_4.4x5mm_Pitch0.65mm

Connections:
+5V: C1.1, C2.1, C3.1, Q1.2 (S), Q2.2 (S), Q3.2 (S), Q4.2 (S), Q5.2 (S), Q6.2 (S), Q7.2 (S), Q8.2 (S), Q9.2 (S), Q10.2 (S), Q11.2 (S), Q12.2 (S), Q13.2 (S), Q14.2 (S), Q15.2 (S), Q16.2 (S), Q17.2 (S), Q18.2 (S), Q19.2 (S), Q20.2 (S), R1.1, R2.1, R3.1, R4.1, R5.1, R6.1, R7.1, R8.1, R9.1, R10.1, R11.1, R12.1, R13.1, R14.1, R15.1, R16.1, R17.1, R18.1, R19.1, R20.1, R49.1, R50.1, R51.1, R52.1, R53.1, R54.1, U2.6 (E3), U2.16 (VCC), U3.6 (E3), U3.16 (VCC), U4.6 (E3), U4.16 (VCC); also elsewhere on the board
/grid/B1: D26.1 (K), D28.1 (K), D30.1 (K), D32.1 (K), D58.1 (K), D60.1 (K), D62.1 (K), D64.1 (K), D90.1 (K), D92.1 (K), D94.1 (K), D96.1 (K), D122.1 (K), D124.1 (K), D126.1 (K), D128.1 (K), D131.1 (K), D141.1 (K), D155.1 (K), D157.1 (K), R24.1
/grid/B2: D18.1 (K), D20.1 (K), D22.1 (K), D24.1 (K), D50.1 (K), D52.1 (K), D54.1 (K), D56.1 (K), D82.1 (K), D84.1 (K), D86.1 (K), D88.1 (K), D114.1 (K), D116.1 (K), D118.1 (K), D120.1 (K), D137.1 (K), D138.1 (K), D151.1 (K), D153.1 (K), R23.1
/grid/B3: D10.1 (K), D12.1 (K), D14.1 (K), D16.1 (K), D42.1 (K), D44.1 (K), D46.1 (K), D48.1 (K), D74.1 (K), D76.1 (K), D78.1 (K), D80.1 (K), D106.1 (K), D108.1 (K), D110.1 (K), D112.1 (K), D133.1 (K), D135.1 (K), D147.1 (K), D149.1 (K), R22.1
/grid/B4: D2.1 (K), D4.1 (K), D6.1 (K), D8.1 (K), D34.1 (K), D36.1 (K), D38.1 (K), D40.1 (K), D66.1 (K), D68.1 (K), D70.1 (K), D72.1 (K), D98.1 (K), D100.1 (K), D102.1 (K), D104.1 (K), D130.1 (K), D139.1 (K), D143.1 (K), D145.1 (K), R21.1
/grid/G1: Q1.1 (G), R1.2, U2.15 (O0)
/grid/G2: Q3.1 (G), R3.2, U2.14 (O1)
/grid/G3: Q5.1 (G), R5.2, U2.13 (O2)
/grid/G4: Q7.1 (G), R7.2, U2.12 (O3)
/grid/G5: Q9.1 (G), R9.2, U2.11 (O4)
/grid/G6: Q11.1 (G), R11.2, U2.10 (O5)
/grid/G7: Q13.1 (G), R13.2, U2.9 (O6)
/grid/G8: Q15.1 (G), R15.2, U2.7 (O7)
/grid/G9: Q2.1 (G), R2.2, U3.15 (O0)
/grid/G10: Q4.1 (G), R4.2, U3.14 (O1)
/grid/G11: Q6.1 (G), R6.2, U3.13 (O2)
/grid/G12: Q8.1 (G), R8.2, U3.12 (O3)
/grid/G13: Q10.1 (G), R10.2, U3.11 (O4)
/grid/G14: Q12.1 (G), R12.2, U3.10 (O5)
/grid/G15: Q14.1 (G), R14.2, U3.9 (O6)
/grid/G16: Q16.1 (G), R16.2, U3.7 (O7)
/grid/G17: Q17.1 (G), R17.2, U4.15 (O0)
/grid/G18: Q18.1 (G), R18.2, U4.14 (O1)
/grid/G19: Q19.1 (G), R19.2, U4.13 (O2)
/grid/G20: Q20.1 (G), R20.2, U4.12 (O3)
/grid/GRID_BUTTON1: R24.2; also elsewhere on the board
/grid/GRID_BUTTON2: R23.2; also elsewhere on the board
/grid/GRID_BUTTON3: R22.2; also elsewhere on the board
/grid/GRID_BUTTON4: R21.2; also elsewhere on the board
/grid/K_BLUE1: D25.4 (BK), D27.4 (BK), D29.4 (BK), D31.4 (BK), D57.4 (BK), D59.4 (BK), D61.4 (BK), D63.4 (BK), D89.4 (BK), D91.4 (BK), D93.4 (BK), D95.4 (BK), D121.4 (BK), D123.4 (BK), D125.4 (BK), D127.4 (BK), D134.4 (BK), D140.4 (BK), D154.4 (BK), D156.4 (BK), R44.1
/grid/K_BLUE2: D17.4 (BK), D19.4 (BK), D21.4 (BK), D23.4 (BK), D49.4 (BK), D51.4 (BK), D53.4 (BK), D55.4 (BK), D81.4 (BK), D83.4 (BK), D85.4 (BK), D87.4 (BK), D113.4 (BK), D115.4 (BK), D117.4 (BK), D119.4 (BK), D136.4 (BK), D150.4 (BK), D152.4 (BK), R43.1
/grid/K_BLUE3: D9.4 (BK), D11.4 (BK), D13.4 (BK), D15.4 (BK), D41.4 (BK), D43.4 (BK), D45.4 (BK), D47.4 (BK), D73.4 (BK), D75.4 (BK), D77.4 (BK), D79.4 (BK), D105.4 (BK), D107.4 (BK), D109.4 (BK), D111.4 (BK), D132.4 (BK), D146.4 (BK), D148.4 (BK), R42.1
/grid/K_BLUE4: D1.4 (BK), D3.4 (BK), D5.4 (BK), D7.4 (BK), D33.4 (BK), D35.4 (BK), D37.4 (BK), D39.4 (BK), D65.4 (BK), D67.4 (BK), D69.4 (BK), D71.4 (BK), D97.4 (BK), D99.4 (BK), D101.4 (BK), D103.4 (BK), D129.4 (BK), D142.4 (BK), D144.4 (BK), R41.1
/grid/K_GREEN1: D25.3 (GK), D27.3 (GK), D29.3 (GK), D31.3 (GK), D57.3 (GK), D59.3 (GK), D61.3 (GK), D63.3 (GK), D89.3 (GK), D91.3 (GK), D93.3 (GK), D95.3 (GK), D121.3 (GK), D123.3 (GK), D125.3 (GK), D127.3 (GK), D134.3 (GK), D140.3 (GK), D154.3 (GK), D156.3 (GK), R36.1
/grid/K_GREEN2: D17.3 (GK), D19.3 (GK), D21.3 (GK), D23.3 (GK), D49.3 (GK), D51.3 (GK), D53.3 (GK), D55.3 (GK), D81.3 (GK), D83.3 (GK), D85.3 (GK), D87.3 (GK), D113.3 (GK), D115.3 (GK), D117.3 (GK), D119.3 (GK), D136.3 (GK), D150.3 (GK), D152.3 (GK), R35.1
/grid/K_GREEN3: D9.3 (GK), D11.3 (GK), D13.3 (GK), D15.3 (GK), D41.3 (GK), D43.3 (GK), D45.3 (GK), D47.3 (GK), D73.3 (GK), D75.3 (GK), D77.3 (GK), D79.3 (GK), D105.3 (GK), D107.3 (GK), D109.3 (GK), D111.3 (GK), D132.3 (GK), D146.3 (GK), D148.3 (GK), R34.1
/grid/K_GREEN4: D1.3 (GK), D3.3 (GK), D5.3 (GK), D7.3 (GK), D33.3 (GK), D35.3 (GK), D37.3 (GK), D39.3 (GK), D65.3 (GK), D67.3 (GK), D69.3 (GK), D71.3 (GK), D97.3 (GK), D99.3 (GK), D101.3 (GK), D103.3 (GK), D129.3 (GK), D142.3 (GK), D144.3 (GK), R33.1
/grid/K_RED1: D25.1 (RK), D27.1 (RK), D29.1 (RK), D31.1 (RK), D57.1 (RK), D59.1 (RK), D61.1 (RK), D63.1 (RK), D89.1 (RK), D91.1 (RK), D93.1 (RK), D95.1 (RK), D121.1 (RK), D123.1 (RK), D125.1 (RK), D127.1 (RK), D134.1 (RK), D140.1 (RK), D154.1 (RK), D156.1 (RK), R28.1
/grid/K_RED2: D17.1 (RK), D19.1 (RK), D21.1 (RK), D23.1 (RK), D49.1 (RK), D51.1 (RK), D53.1 (RK), D55.1 (RK), D81.1 (RK), D83.1 (RK), D85.1 (RK), D87.1 (RK), D113.1 (RK), D115.1 (RK), D117.1 (RK), D119.1 (RK), D136.1 (RK), D150.1 (RK), D152.1 (RK), R27.1
/grid/K_RED3: D9.1 (RK), D11.1 (RK), D13.1 (RK), D15.1 (RK), D41.1 (RK), D43.1 (RK), D45.1 (RK), D47.1 (RK), D73.1 (RK), D75.1 (RK), D77.1 (RK), D79.1 (RK), D105.1 (RK), D107.1 (RK), D109.1 (RK), D111.1 (RK), D132.1 (RK), D146.1 (RK), D148.1 (RK), R26.1
/grid/K_RED4: D1.1 (RK), D3.1 (RK), D5.1 (RK), D7.1 (RK), D33.1 (RK), D35.1 (RK), D37.1 (RK), D39.1 (RK), D65.1 (RK), D67.1 (RK), D69.1 (RK), D71.1 (RK), D97.1 (RK), D99.1 (RK), D101.1 (RK), D103.1 (RK), D129.1 (RK), D142.1 (RK), D144.1 (RK), R25.1
/grid/PWM_BLUE1: Q32.1 (G), R48.1; also elsewhere on the board
/grid/PWM_BLUE2: Q31.1 (G), R47.1; also elsewhere on the board
/grid/PWM_BLUE3: Q30.1 (G), R46.1; also elsewhere on the board
/grid/PWM_BLUE4: Q29.1 (G), R45.1; also elsewhere on the board
/grid/PWM_GREEN1: Q28.1 (G), R40.1; also elsewhere on the board
/grid/PWM_GREEN2: Q27.1 (G), R39.1; also elsewhere on the board
/grid/PWM_GREEN3: Q26.1 (G), R38.1; also elsewhere on the board
/grid/PWM_GREEN4: Q25.1 (G), R37.1; also elsewhere on the board
/grid/PWM_RED1: Q24.1 (G), R32.1; also elsewhere on the board
/grid/PWM_RED2: Q23.1 (G), R31.1; also elsewhere on the board
/grid/PWM_RED3: Q22.1 (G), R30.1; also elsewhere on the board
/grid/PWM_RED4: Q21.1 (G), R29.1; also elsewhere on the board
/mcu/COL1: R52.2, U2.1 (A0), U3.1 (A0), U4.1 (A0); also elsewhere on the board
/mcu/COL2: R51.2, U2.2 (A1), U3.2 (A1), U4.2 (A1); also elsewhere on the board
/mcu/COL3: R50.2, U2.3 (A2), U3.3 (A2), U4.3 (A2); also elsewhere on the board
/mcu/COL4: R49.2, U2.5 (E2); also elsewhere on the board
/mcu/COL5: R53.2, U3.5 (E2); also elsewhere on the board
/mcu/COL6: R54.2, U4.5 (E2); also elsewhere on the board
GND: C1.2, C2.2, C3.2, Q21.2 (S), Q22.2 (S), Q23.2 (S), Q24.2 (S), Q25.2 (S), Q26.2 (S), Q27.2 (S), Q28.2 (S), Q29.2 (S), Q30.2 (S), Q31.2 (S), Q32.2 (S), R29.2, R30.2, R31.2, R32.2, R37.2, R38.2, R39.2, R40.2, R45.2, R46.2, R47.2, R48.2, U2.4 (E1), U2.8 (GND), U3.4 (E1), U3.8 (GND), U4.4 (E1), U4.8 (GND); also elsewhere on the board
unnamed: D1.2 (A), D9.2 (A), D17.2 (A), D25.2 (A), Q2.3 (D), SW1.1, SW1.9, SW1.17, SW1.25
unnamed: D2.2 (A), SW1.2
unnamed: D4.2 (A), SW1.4
unnamed: D6.2 (A), SW1.6
unnamed: D8.2 (A), SW1.8
unnamed: D10.2 (A), SW1.10
unnamed: D3.2 (A), D11.2 (A), D19.2 (A), D27.2 (A), Q4.3 (D), SW1.3, SW1.11, SW1.19, SW1.27
unnamed: D12.2 (A), SW1.12
unnamed: D5.2 (A), D13.2 (A), D21.2 (A), D29.2 (A), Q6.3 (D), SW1.5, SW1.13, SW1.21, SW1.29
unnamed: D14.2 (A), SW1.14
unnamed: D7.2 (A), D15.2 (A), D23.2 (A), D31.2 (A), Q8.3 (D), SW1.7, SW1.15, SW1.23, SW1.31
unnamed: D16.2 (A), SW1.16
unnamed: D18.2 (A), SW1.18
unnamed: D20.2 (A), SW1.20
unnamed: D22.2 (A), SW1.22
unnamed: D24.2 (A), SW1.24
unnamed: D26.2 (A), SW1.26
unnamed: D28.2 (A), SW1.28
unnamed: D30.2 (A), SW1.30
unnamed: D32.2 (A), SW1.32
unnamed: D33.2 (A), D41.2 (A), D49.2 (A), D57.2 (A), Q10.3 (D), SW2.1, SW2.9, SW2.17, SW2.25
unnamed: D34.2 (A), SW2.2
unnamed: D35.2 (A), D43.2 (A), D51.2 (A), D59.2 (A), Q12.3 (D), SW2.3, SW2.11, SW2.19, SW2.27
unnamed: D36.2 (A), SW2.4
unnamed: D37.2 (A), D45.2 (A), D53.2 (A), D61.2 (A), Q14.3 (D), SW2.5, SW2.13, SW2.21, SW2.29
unnamed: D38.2 (A), SW2.6
unnamed: D39.2 (A), D47.2 (A), D55.2 (A), D63.2 (A), Q16.3 (D), SW2.7, SW2.15, SW2.23, SW2.31
unnamed: D40.2 (A), SW2.8
unnamed: D42.2 (A), SW2.10
unnamed: D44.2 (A), SW2.12
unnamed: D46.2 (A), SW2.14
unnamed: D48.2 (A), SW2.16
unnamed: D50.2 (A), SW2.18
unnamed: D52.2 (A), SW2.20
unnamed: D54.2 (A), SW2.22
unnamed: D56.2 (A), SW2.24
unnamed: D58.2 (A), SW2.26
unnamed: D60.2 (A), SW2.28
unnamed: D62.2 (A), SW2.30
unnamed: D64.2 (A), SW2.32
unnamed: D65.2 (A), D73.2 (A), D81.2 (A), D89.2 (A), Q1.3 (D), SW3.1, SW3.9, SW3.17, SW3.25
unnamed: D66.2 (A), SW3.2
unnamed: D67.2 (A), D75.2 (A), D83.2 (A), D91.2 (A), Q3.3 (D), SW3.3, SW3.11, SW3.19, SW3.27
unnamed: D68.2 (A), SW3.4
unnamed: D69.2 (A), D77.2 (A), D85.2 (A), D93.2 (A), Q5.3 (D), SW3.5, SW3.13, SW3.21, SW3.29
unnamed: D70.2 (A), SW3.6
unnamed: D71.2 (A), D79.2 (A), D87.2 (A), D95.2 (A), Q7.3 (D), SW3.7, SW3.15, SW3.23, SW3.31
unnamed: D72.2 (A), SW3.8
unnamed: D74.2 (A), SW3.10
unnamed: D76.2 (A), SW3.12
unnamed: D78.2 (A), SW3.14
unnamed: D80.2 (A), SW3.16
unnamed: D82.2 (A), SW3.18
unnamed: D84.2 (A), SW3.20
unnamed: D86.2 (A), SW3.22
unnamed: D88.2 (A), SW3.24
unnamed: D90.2 (A), SW3.26
unnamed: D92.2 (A), SW3.28
unnamed: D94.2 (A), SW3.30
unnamed: D96.2 (A), SW3.32
unnamed: D98.2 (A), SW4.2
unnamed: D100.2 (A), SW4.4
unnamed: D101.2 (A), D109.2 (A), D117.2 (A), D125.2 (A), Q13.3 (D), SW4.5, SW4.13, SW4.21, SW4.29
unnamed: D102.2 (A), SW4.6
unnamed: D103.2 (A), D111.2 (A), D119.2 (A), D127.2 (A), Q15.3 (D), SW4.7, SW4.15, SW4.23, SW4.31
unnamed: D104.2 (A), SW4.8
unnamed: D97.2 (A), D105.2 (A), D113.2 (A), D121.2 (A), Q9.3 (D), SW4.1, SW4.9, SW4.17, SW4.25
unnamed: D106.2 (A), SW4.10
unnamed: D99.2 (A), D107.2 (A), D115.2 (A), D123.2 (A), Q11.3 (D), SW4.3, SW4.11, SW4.19, SW4.27
unnamed: D108.2 (A), SW4.12
unnamed: D110.2 (A), SW4.14
unnamed: D112.2 (A), SW4.16
unnamed: D114.2 (A), SW4.18
unnamed: D116.2 (A), SW4.20
unnamed: D118.2 (A), SW4.22
unnamed: D120.2 (A), SW4.24
unnamed: D122.2 (A), SW4.26
unnamed: D124.2 (A), SW4.28
unnamed: D126.2 (A), SW4.30
unnamed: D128.2 (A), SW4.32
unnamed: D129.2 (A), D132.2 (A), D136.2 (A), D140.2 (A), Q18.3 (D), SW5.2, SW7.2, SW10.2, SW12.2
unnamed: D130.2 (A), SW5.1
unnamed: D131.2 (A), SW6.2
unnamed: D133.2 (A), SW7.1
unnamed: D134.2 (A), Q20.3 (D), SW6.1, SW8.2, SW9.1, SW11.1
unnamed: D135.2 (A), SW9.2
unnamed: D137.2 (A), SW10.1
unnamed: D138.2 (A), SW8.1
unnamed: D139.2 (A), SW11.2
unnamed: D141.2 (A), SW12.1
unnamed: D142.2 (A), D148.2 (A), D150.2 (A), D156.2 (A), Q17.3 (D), SW13.2, SW16.2, SW17.2, SW20.2
unnamed: D143.2 (A), SW13.1
unnamed: D144.2 (A), D146.2 (A), D152.2 (A), D154.2 (A), Q19.3 (D), SW14.2, SW15.2, SW18.2, SW19.2
unnamed: D145.2 (A), SW14.1
unnamed: D147.2 (A), SW15.1
unnamed: D149.2 (A), SW16.1
unnamed: D151.2 (A), SW17.1
unnamed: D153.2 (A), SW18.1
unnamed: D155.2 (A), SW19.1
unnamed: D157.2 (A), SW20.1
unnamed: Q21.3 (D), R25.2
unnamed: Q22.3 (D), R26.2
unnamed: Q23.3 (D), R27.2
unnamed: Q24.3 (D), R28.2
unnamed: Q25.3 (D), R33.2
unnamed: Q26.3 (D), R34.2
unnamed: Q27.3 (D), R35.2
unnamed: Q28.3 (D), R36.2
unnamed: Q29.3 (D), R41.2
unnamed: Q30.3 (D), R42.2
unnamed: Q31.3 (D), R43.2
unnamed: Q32.3 (D), R44.2

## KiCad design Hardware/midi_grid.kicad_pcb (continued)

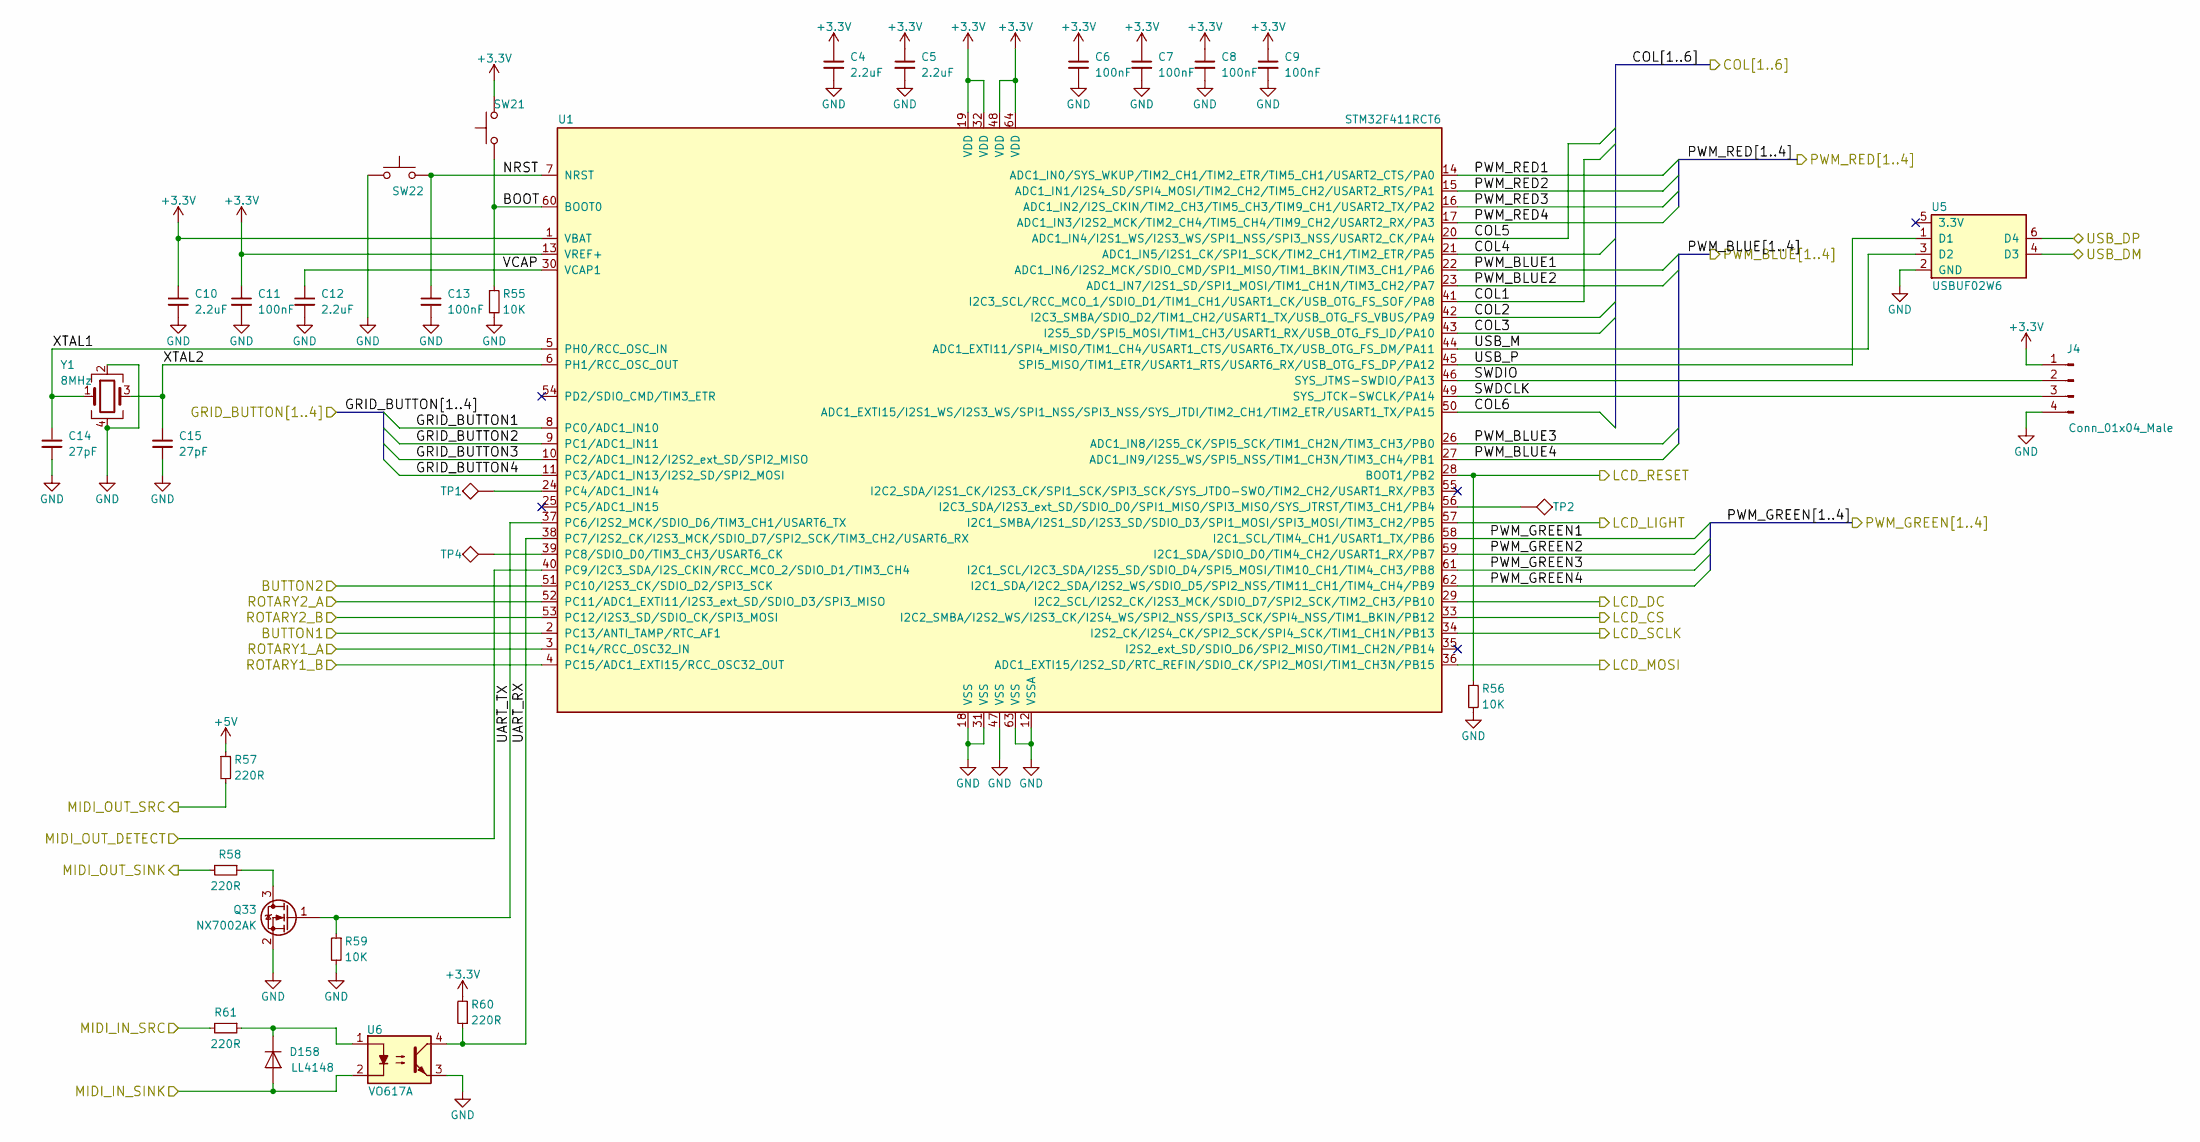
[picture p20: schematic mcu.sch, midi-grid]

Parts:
C4, C5, C10, C12: 2.2uF; C_0603
C6, C7, C8, C9, C11, C13: 100nF; C_0603
C14, C15: 27pF; C_0603
D158: LL4148; D_MiniMELF
J4: Conn_01x04_Male; Molex_KK-6410-04_04x2.54mm_Straight
Q33: NX7002AK; SOT-23
R55, R56, R59: 10K; R_0603
R57, R58, R60, R61: 220R; R_0603
SW21, SW22: SW_Push; SW_SPST_PTS645
TP1, TP2, TP4: TEST; Test_Point_Pad_d3.0mm
U1: STM32F411RCT6; LQFP-64_10x10mm_Pitch0.5mm
U5: USBUF02W6; SOT-363_SC-70-6
U6: VO617A; DIP4-smd
Y1: 8MHz; Oscillator_SMD_EuroQuartz_XO53-4pin_5.0x3.2mm_HandSoldering

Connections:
+3V3: C4.1, C5.1, C6.1, C7.1, C8.1, C9.1, C10.1, C11.1, J4.1, R60.2, SW21.2, U1.1 (VBAT), U1.13 (VREF+), U1.19 (VDD), U1.32 (VDD), U1.48 (VDD), U1.64 (VDD); also elsewhere on the board
+5V: R57.1; also elsewhere on the board
/digital_io/BUTTON1: U1.2 (PC13/ANTI_TAMP/RTC_AF1); also elsewhere on the board
/digital_io/BUTTON2: U1.51 (PC10/I2S3_CK/SDIO_D2/SPI3_SCK); also elsewhere on the board
/digital_io/LCD_CS: U1.33 (I2C2_SMBA/I2S2_WS/I2S3_CK/I2S4_WS/SPI2_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); also elsewhere on the board
/digital_io/LCD_DC: U1.29 (I2C2_SCL/I2S2_CK/I2S3_MCK/SDIO_D7/SPI2_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); also elsewhere on the board
/digital_io/LCD_LIGHT: U1.57 (I2C1_SMBA/I2S1_SD/I2S3_SD/SDIO_D3/SPI1_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); also elsewhere on the board
/digital_io/LCD_MOSI: U1.36 (ADC1_EXTI15/I2S2_SD/RTC_REFIN/SDIO_CK/S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); also elsewhere on the board
/digital_io/LCD_RESET: R56.1, U1.28 (BOOT1/PB2); also elsewhere on the board
/digital_io/LCD_SCLK: U1.34 (I2S2_CK/I2S4_CK/SPI2_SCK/SPI4_SCK/TIM1_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); also elsewhere on the board
/digital_io/ROTARY1_A: U1.3 (PC14/RCC_OSC32_IN); also elsewhere on the board
/digital_io/ROTARY1_B: U1.4 (PC15/ADC1_EXTI15/RCC_OSC32_OUT); also elsewhere on the board
/digital_io/ROTARY2_A: U1.52 (PC11/ADC1_EXTI11/I2S3_ext_SD/SDIO_D3/SP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); also elsewhere on the board
/digital_io/ROTARY2_B: U1.53 (PC12/I2S3_SD/SDIO_CK/SPI3_MOSI); also elsewhere on the board
/grid/GRID_BUTTON1: U1.8 (PC0/ADC1_IN10); also elsewhere on the board
/grid/GRID_BUTTON2: U1.9 (PC1/ADC1_IN11); also elsewhere on the board
/grid/GRID_BUTTON3: U1.10 (PC2/ADC1_IN12/I2S2_ext_SD/SPI2_MISO); also elsewhere on the board
/grid/GRID_BUTTON4: U1.11 (PC3/ADC1_IN13/I2S2_SD/SPI2_MOSI); also elsewhere on the board
/grid/PWM_BLUE1: U1.22 (ADC1_IN6/I2S2_MCK/SDIO_CMD/SPI1_MISO/TI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); also elsewhere on the board
/grid/PWM_BLUE2: U1.23 (ADC1_IN7/I2S1_SD/SPI1_MOSI/TIM1_CH1N/TI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); also elsewhere on the board
/grid/PWM_BLUE3: U1.26 (ADC1_IN8/I2S5_CK/SPI5_SCK/TIM1_CH2N/TIM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); also elsewhere on the board
/grid/PWM_BLUE4: U1.27 (ADC1_IN9/I2S5_WS/SPI5_NSS/TIM1_CH3N/TIM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); also elsewhere on the board
/grid/PWM_GREEN1: U1.58 (I2C1_SCL/TIM4_CH1/USART1_TX/PB6); also elsewhere on the board
/grid/PWM_GREEN2: U1.59 (I2C1_SDA/SDIO_D0/TIM4_CH2/USART1_RX/PB7); also elsewhere on the board
/grid/PWM_GREEN3: U1.61 (I2C1_SCL/I2C3_SDA/I2S5_SD/SDIO_D4/SPI5_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); also elsewhere on the board
/grid/PWM_GREEN4: U1.62 (I2C1_SDA/I2C2_SDA/I2S2_WS/SDIO_D5/SPI2_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); also elsewhere on the board
/grid/PWM_RED1: U1.14 (ADC1_IN0/SYS_WKUP/TIM2_CH1/TIM2_ETR/TIM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); also elsewhere on the board
/grid/PWM_RED2: U1.15 (ADC1_IN1/I2S4_SD/SPI4_MOSI/TIM2_CH2/TIM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); also elsewhere on the board
/grid/PWM_RED3: U1.16 (ADC1_IN2/I2S_CKIN/TIM2_CH3/TIM5_CH3/TIM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); also elsewhere on the board
/grid/PWM_RED4: U1.17 (ADC1_IN3/I2S2_MCK/TIM2_CH4/TIM5_CH4/TIM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); also elsewhere on the board
/mcu/BOOT: R55.1, SW21.1, U1.60 (BOOT0)
/mcu/COL1: U1.41 (I2C3_SCL/RCC_MCO_1/SDIO_D1/TIM1_CH1/USA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); also elsewhere on the board
/mcu/COL2: U1.42 (I2C3_SMBA/SDIO_D2/TIM1_CH2/USART1_TX/US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); also elsewhere on the board
/mcu/COL3: U1.43 (I2S5_SD/SPI5_MOSI/TIM1_CH3/USART1_RX/US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); also elsewhere on the board
/mcu/COL4: U1.21 (ADC1_IN5/I2S1_CK/SPI1_SCK/TIM2_CH1/TIM2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); also elsewhere on the board
/mcu/COL5: U1.20 (ADC1_IN4/I2S1_WS/I2S3_WS/SPI1_NSS/SPI3_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); also elsewhere on the board
/mcu/COL6: U1.50 (ADC1_EXTI15/I2S1_WS/I2S3_WS/SPI1_NSS/SP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); also elsewhere on the board
/mcu/MIDI_IN_SINK: D158.2 (A), U6.2; also elsewhere on the board
/mcu/MIDI_IN_SRC: R61.2; also elsewhere on the board
/mcu/MIDI_OUT_DETECT: U1.40 (PC9/I2C3_SDA/I2S_CKIN/RCC_MCO_2/SDIO_D1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); also elsewhere on the board
/mcu/MIDI_OUT_SINK: R58.2; also elsewhere on the board
/mcu/MIDI_OUT_SRC: R57.2; also elsewhere on the board
/mcu/NRST: C13.1, SW22.2, U1.7 (NRST)
/mcu/SWDCLK: J4.3, U1.49 (SYS_JTCK-SWCLK/PA14)
/mcu/SWDIO: J4.2, U1.46 (SYS_JTMS-SWDIO/PA13)
/mcu/UART_RX: R60.1, U1.38 (PC7/I2S2_CK/I2S3_MCK/SDIO_D7/SPI2_SCK/T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), U6.4
/mcu/UART_TX: Q33.1 (G), R59.1, U1.37 (PC6/I2S2_MCK/SDIO_D6/TIM3_CH1/USART6_TX)
/mcu/USB_DM: U5.4 (D3); also elsewhere on the board
/mcu/USB_DP: U5.6 (D4); also elsewhere on the board
/mcu/USB_M: U1.44 (ADC1_EXTI11/SPI4_MISO/TIM1_CH4/USART1_C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), U5.3 (D2)
/mcu/USB_P: U1.45 (SPI5_MISO/TIM1_ETR/USART1_RTS/USART6_RX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), U5.1 (D1)
/mcu/VCAP: C12.1, U1.30 (VCAP1)
/mcu/XTAL1: C14.1, U1.5 (PH0/RCC_OSC_IN), Y1.1
/mcu/XTAL2: C15.1, U1.6 (PH1/RCC_OSC_OUT), Y1.3
GND: C4.2, C5.2, C6.2, C7.2, C8.2, C9.2, C10.2, C11.2, C12.2, C13.2, C14.2, C15.2, J4.4, Q33.2 (S), R55.2, R56.2, R59.2, SW22.1, U1.12 (VSSA), U1.18 (VSS), U1.31 (VSS), U1.47 (VSS), U1.63 (VSS), U5.2 (GND), U6.3, Y1.2, Y1.4; also elsewhere on the board
unnamed: D158.1 (K), R61.1, U6.1
unnamed: Q33.3 (D), R58.1
unnamed: TP1.1, U1.24 (PC4/ADC1_IN14)
unnamed: TP2.1, U1.56 (I2C3_SDA/I2S3_ext_SD/SDIO_D0/SPI1_MISO/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)
unnamed: TP4.1, U1.39 (PC8/SDIO_D0/TIM3_CH3/USART6_CK)

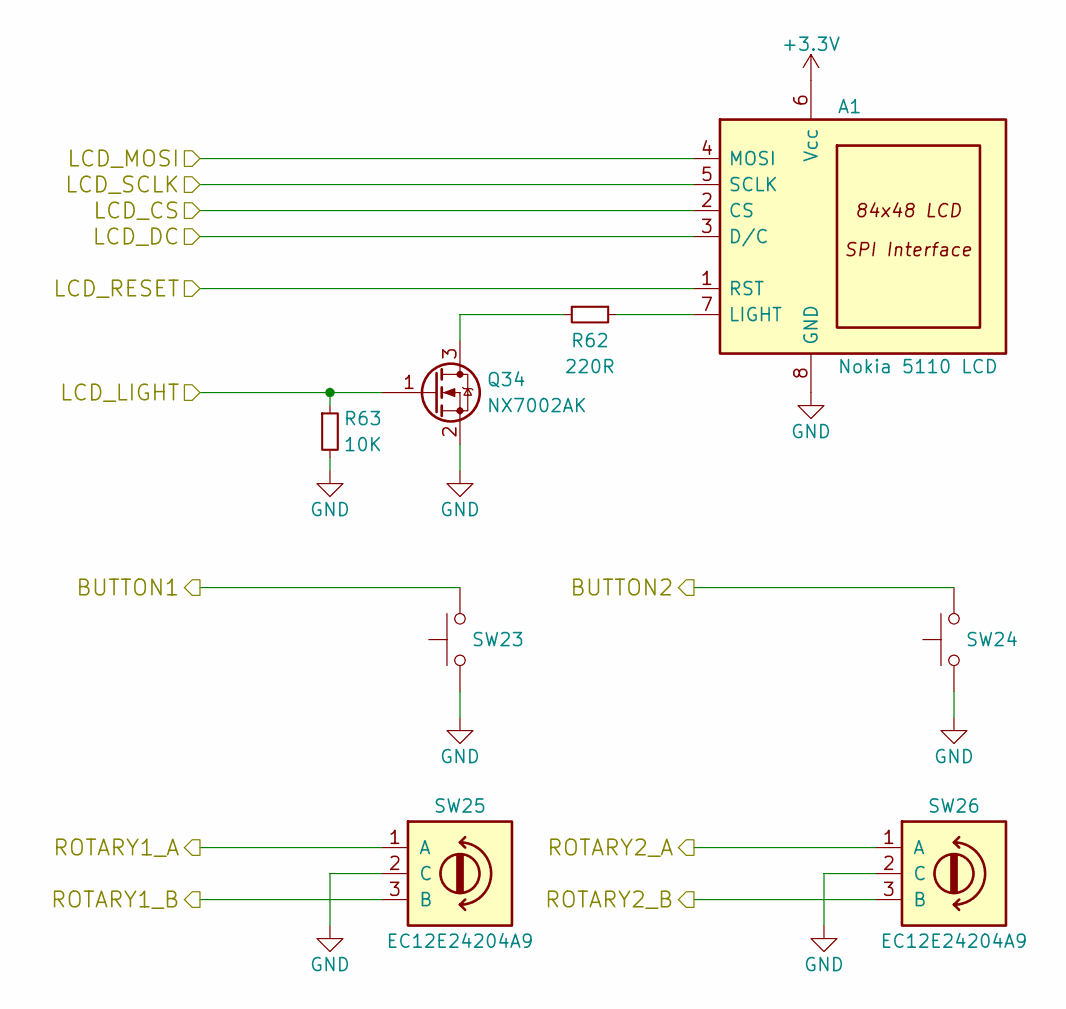
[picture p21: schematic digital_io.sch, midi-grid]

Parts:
A1: Nokia 5110 LCD; Nokia_5110_lcd
Q34: NX7002AK; SOT-23
R62: 220R; R_0603
R63: 10K; R_0603
SW23, SW24: SW_Push; Tactile_switch_12x12
SW25, SW26: EC12E24204A9; EC12

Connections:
+3V3: A1.6 (Vcc); also elsewhere on the board
/digital_io/BUTTON1: SW23.2; also elsewhere on the board
/digital_io/BUTTON2: SW24.2; also elsewhere on the board
/digital_io/LCD_CS: A1.2 (CS); also elsewhere on the board
/digital_io/LCD_DC: A1.3 (D/C); also elsewhere on the board
/digital_io/LCD_LIGHT: Q34.1 (G), R63.1; also elsewhere on the board
/digital_io/LCD_MOSI: A1.4 (MOSI); also elsewhere on the board
/digital_io/LCD_RESET: A1.1 (RST); also elsewhere on the board
/digital_io/LCD_SCLK: A1.5 (SCLK); also elsewhere on the board
/digital_io/ROTARY1_A: SW25.1 (A); also elsewhere on the board
/digital_io/ROTARY1_B: SW25.3 (B); also elsewhere on the board
/digital_io/ROTARY2_A: SW26.1 (A); also elsewhere on the board
/digital_io/ROTARY2_B: SW26.3 (B); also elsewhere on the board
GND: A1.8 (GND), Q34.2 (S), R63.2, SW23.1, SW24.1, SW25.2 (C), SW26.2 (C); also elsewhere on the board
unnamed: A1.7 (LIGHT), R62.1
unnamed: Q34.3 (D), R62.2

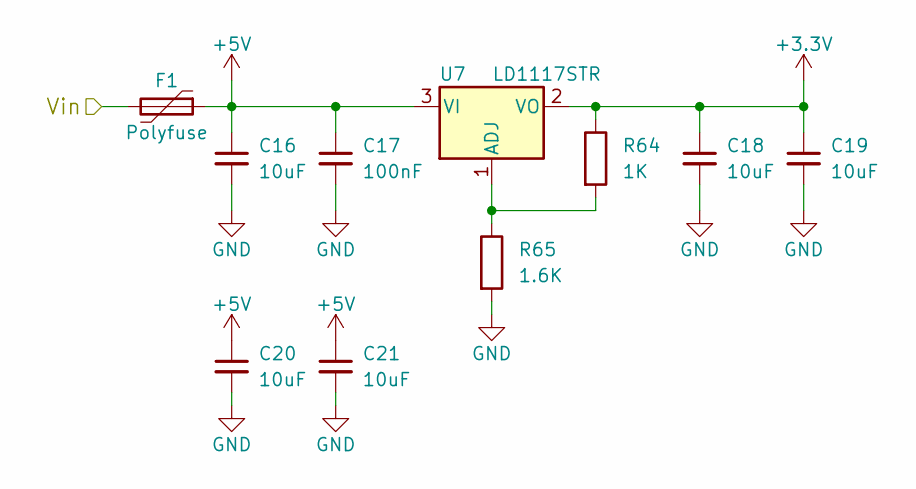
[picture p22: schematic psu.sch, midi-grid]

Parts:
C16, C18, C19, C20, C21: 10uF; C_1206
C17: 100nF; C_0603
F1: Polyfuse; R_1206
R64: 1K; R_0603
R65: 1.6K; R_0603
U7: LD1117STR; SOT-223-3Lead_TabPin2

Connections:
+3V3: C18.1, C19.1, R64.1, U7.2 (VO); also elsewhere on the board
+5V: C16.1, C17.1, C20.1, C21.1, F1.1, U7.3 (VI); also elsewhere on the board
/psu/Vin: F1.2; also elsewhere on the board
GND: C16.2, C17.2, C18.2, C19.2, C20.2, C21.2, R65.2; also elsewhere on the board
unnamed: R64.2, R65.1, U7.1 (ADJ)

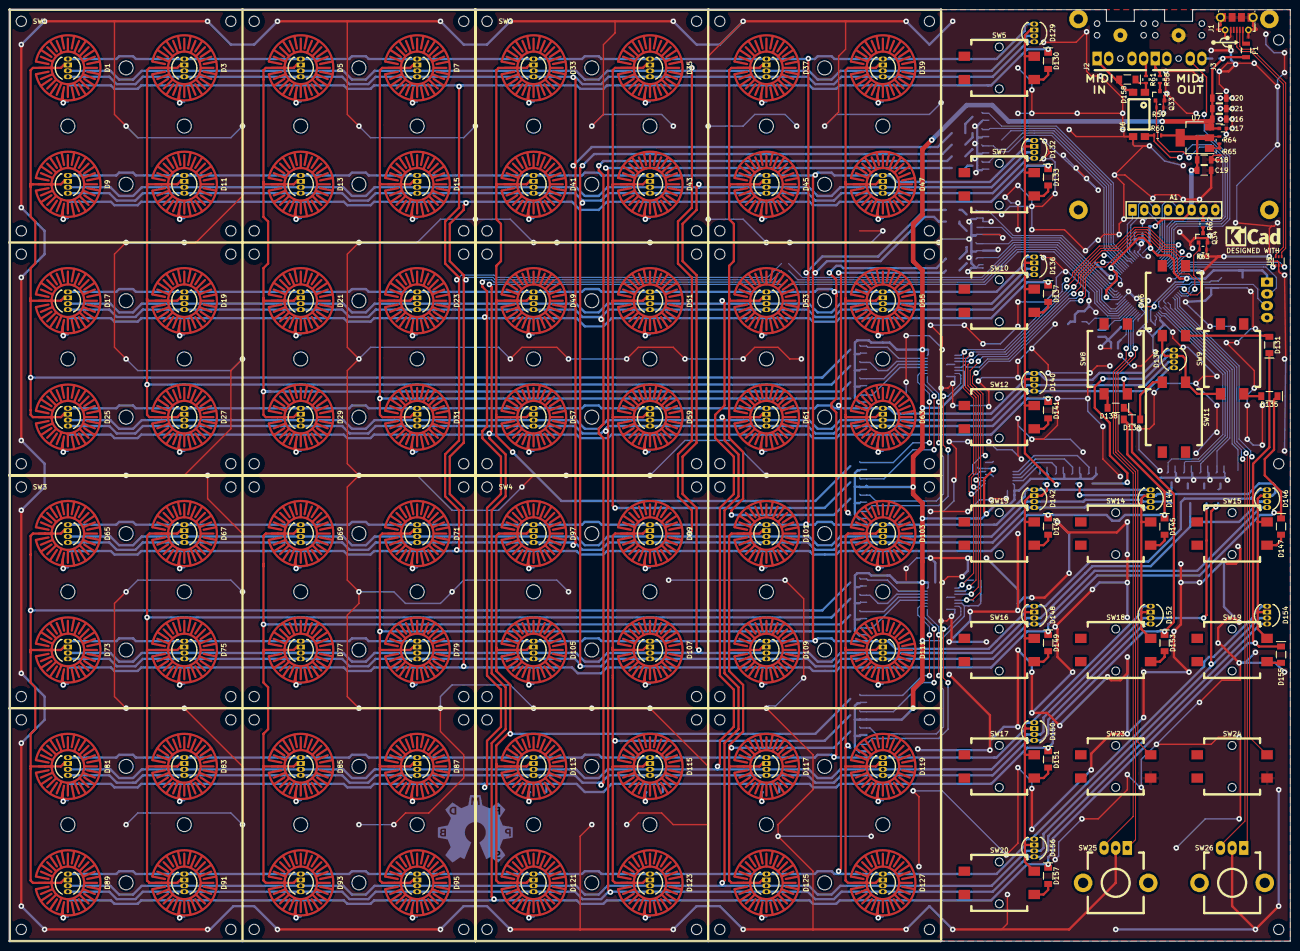
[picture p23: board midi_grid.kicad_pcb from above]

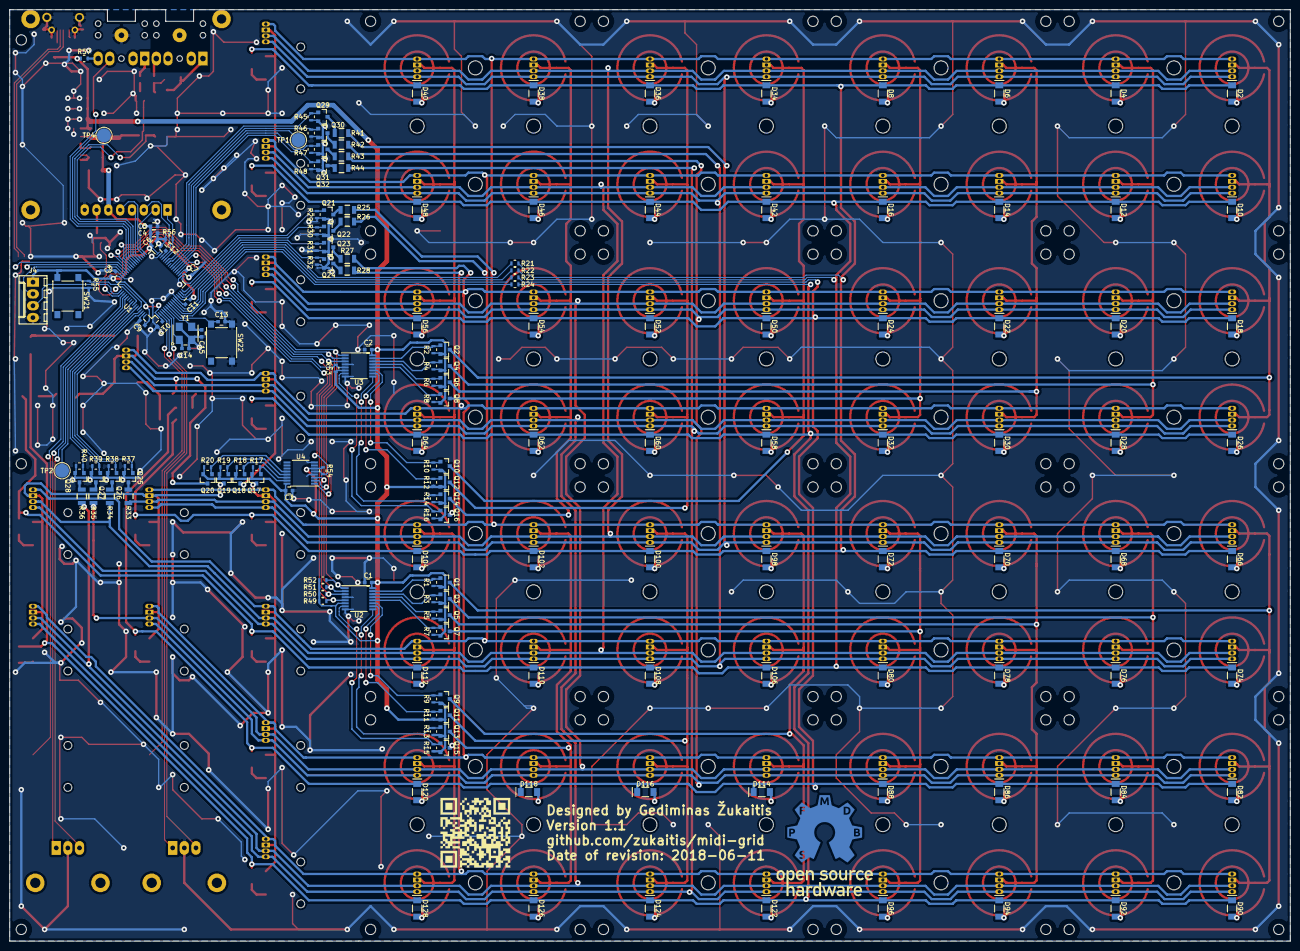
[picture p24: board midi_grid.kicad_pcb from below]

Board: 2 copper layers, 275.0 x 200.0 mm, 328 parts (181 on the bottom side), 212 nets.

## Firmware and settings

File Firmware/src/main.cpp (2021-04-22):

#include "main.hpp"
#include <freertos/ticks.hpp>

#include "stm32f4xx_hal.h"

#ifdef USE_SEMIHOSTING
extern void initialise_monitor_handles(void);
#endif


int main()
{
    Main& main = Main::getInstance();
    main.run();
}

Main::Main() :
        system_( mcu::System() ),
        globalInterrupts_( mcu::GlobalInterrupts() ),
        gridDriver_( hardware::grid::GridDriver() ),
        gridContainer_( grid::GridContainer( &gridDriver_, &gridDriver_, &globalInterrupts_ ) ),
        additionalButtons_( additional_buttons::AdditionalButtons( &gridDriver_ ) ),
        rotaryControls_( rotary_controls::RotaryControls( &gridDriver_ ) ),
        usbMidi_( midi::UsbMidi() ),
        lcdSpi_( hardware::lcd::Spi() ),
        backlightDriver_( hardware::lcd::BacklightDriver() ),
        lcdContainer_( &lcdSpi_, &backlightDriver_ ),
        testing_( &gridDriver_ ),
        logContainer_( &lcdContainer_.getLcdHighPriority() ),
        applicationController_( application::ApplicationController(
            &additionalButtons_, &gridContainer_.getGrid(), &rotaryControls_, &usbMidi_ ) ),
        startup_( applicationController_, gridDriver_, lcdContainer_.getLcdLowPriority(), system_ ),
        gridTest_( applicationController_, gridContainer_.getGrid(), lcdContainer_.getLcdLowPriority(), usbMidi_ ),
        internalMenu_( applicationController_, gridContainer_.getGrid(), additionalButtons_,
            lcdContainer_.getLcdHighPriority(), system_ ),
        launchpad_( &applicationController_, &gridContainer_.getGrid(), &additionalButtons_, &rotaryControls_, &lcdContainer_.getLcdLowPriority(),
            &usbMidi_, &system_, &testing_ ),
        snake_( applicationController_, gridContainer_.getGrid(), lcdContainer_.getLcdLowPriority() )
{
    etl::array<application::Application*, application::kNumberOfApplications> applicationList = {
        nullptr, // ApplicationIndex_PREVIOUS
        &startup_, // ApplicationIndex_STARTUP
        &gridTest_, // ApplicationIndex_GRID_TEST
        &internalMenu_, // ApplicationIndex_INTERNAL_MENU
        &launchpad_, // ApplicationIndex_LAUNCHPAD
        &snake_ // ApplicationIndex_SNAKE
    };

    applicationController_.initialize( applicationList );
}

syslog::LogContainer& Main::getLogContainer()
{
    return logContainer_;
}

void Main::run()
{
    // globalInterrupts_.disable();
    system_.initialize();

    //applicationController_.selectApplication( application::ApplicationIndex_STARTUP );
    freertos::Thread::StartScheduler();
}

extern "C" void vApplicationStackOverflowHook( TaskHandle_t xTask, char *pcTaskName )
{
    volatile uint32_t i = 0;
    while (true)
    {
        i++;
    }
}

extern "C" void vApplicationMallocFailedHook()
{
    volatile uint32_t i = 0;
    while (true)
    {
        i++;
    }
}

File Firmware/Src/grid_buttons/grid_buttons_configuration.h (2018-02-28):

/*
 * grid_buttons_init.h
 *
 *  Created on: 2018-01-29
 *      Author: Gedas
 */
#ifndef GRID_BUTTONS_GRID_BUTTONS_INIT_H_
#define GRID_BUTTONS_GRID_BUTTONS_INIT_H_

#include "grid_buttons/grid_buttons.h"
#include "stm32f4xx_hal.h"

#define GRID_BUTTON_IN_GPIO_PORT GPIOC
#define BUTTON_IN1_Pin GPIO_PIN_13
#define BUTTON_IN2_Pin GPIO_PIN_10
#define ROTARY1_A_Pin GPIO_PIN_14
#define ROTARY1_B_Pin GPIO_PIN_15
#define ROTARY2_A_Pin GPIO_PIN_11
#define ROTARY2_B_Pin GPIO_PIN_12
#define GRID_BUTTON_IN1_Pin GPIO_PIN_0
#define GRID_BUTTON_IN2_Pin GPIO_PIN_1
#define GRID_BUTTON_IN3_Pin GPIO_PIN_2
#define GRID_BUTTON_IN4_Pin GPIO_PIN_3

#define GRID_COLUMN_CONTROL_GPIO_PORT GPIOA
#define GRID_COLUMN_OUT1_Pin GPIO_PIN_8
#define GRID_COLUMN_OUT2_Pin GPIO_PIN_9
#define GRID_COLUMN_OUT3_Pin GPIO_PIN_10
#define GRID_COLUMN_OUT4_Pin GPIO_PIN_5
#define GRID_COLUMN_OUT5_Pin GPIO_PIN_4
#define GRID_COLUMN_OUT6_Pin GPIO_PIN_15

#define PWM_RED_GPIO_PORT GPIOA
#define PWM_RED1_Pin GPIO_PIN_0
#define PWM_RED2_Pin GPIO_PIN_1
#define PWM_RED3_Pin GPIO_PIN_2
#define PWM_RED4_Pin GPIO_PIN_3

#define PWM_GREEN_GPIO_PORT GPIOB
#define PWM_GREEN1_Pin GPIO_PIN_6
#define PWM_GREEN2_Pin GPIO_PIN_7
#define PWM_GREEN3_Pin GPIO_PIN_8
#define PWM_GREEN4_Pin GPIO_PIN_9

#define PWM_BLUE1_2_GPIO_PORT GPIOA
#define PWM_BLUE1_Pin GPIO_PIN_6
#define PWM_BLUE2_Pin GPIO_PIN_7
#define PWM_BLUE3_4_GPIO_PORT GPIOB
#define PWM_BLUE3_Pin GPIO_PIN_0
#define PWM_BLUE4_Pin GPIO_PIN_1

#define PWM_TIMER_RED           TIM2
#define PWM_TIMER_GREEN         TIM4
#define PWM_TIMER_BLUE          TIM3
#define BASE_INTERRUPT_TIMER    TIM10

#define NUMBER_OF_ROWS      4
#define NUMBER_OF_COLUMNS   20
#define NUMBER_OF_BUTTON_DEBOUNCING_CYCLES 2

#define LED_FLASH_PERIOD_MS         250 // 120bpm - default flashing rate
#define LED_PULSE_STEP_COUNT        15
#define LED_PULSE_STEP_PERIOD_MS    67  // 1000ms / 15 = 66.6... ms

#define PWM_CLOCK_PERIOD 47000 // <500us - has to be shorter than base period

#define GRID_BUTTON_MASK 0x000F

static const uint16_t columnSelectValue[NUMBER_OF_COLUMNS] = {  0xF8DF, 0xF9DF, 0xFADF, 0xFBDF,
                                                                0xFCDF, 0xFDDF, 0xFEDF, 0xFFDF,
                                                                0x78FF, 0x7AFF, 0xF8EF, 0xF9EF,
                                                                0xFAEF, 0xFBEF, 0xFCEF, 0xFDEF,
                                                                0xFEEF, 0xFFEF, 0x79FF, 0x7BFF };

static const uint32_t baseInterruptClockPrescaler = 96; // 1us
static const uint32_t baseInterruptClockPeriod = 500; // 500us

static const uint16_t brightnessPad[65] = {
        47000, 46662, 46365, 46057, 45727, 45373, 44999, 44607,
        44195, 43763, 43317, 42851, 42373, 41879, 41359, 40843,
        40287, 39741, 39177, 38600, 37993, 37397, 36771, 36144,
        35499, 34851, 34185, 33501, 32796, 32108, 31429, 30721,
        29973, 29231, 28494, 27733, 26952, 26156, 25383, 24564,
        23781, 22934, 22103, 21275, 20401, 19570, 18699, 17802,
        16959, 16053, 15165, 14210, 13317, 12399, 11433, 10421,
        9485, 8522, 7585, 6597, 5642, 4627, 3641, 2591, 1001 };

static const uint16_t brightnessDirect[65] = {
        47000, 46777, 46692, 46603, 46506, 46402, 46291, 46175,
        46053, 45925, 45792, 45652, 45509, 45361, 45207, 45050,
        44887, 44721, 44552, 44379, 44198, 44019, 43836, 43646,
        43458, 43262, 43069, 42867, 42663, 42458, 42252, 42048,
        41834, 41618, 41409, 41191, 40968, 40741, 40527, 40301,
        40078, 39845, 39615, 39393, 39144, 38921, 38681, 38449,
        38217, 37979, 37735, 37500, 37247, 37005, 36767, 36511,
        36263, 36011, 35787, 35511, 35271, 35013, 34797, 34520, 34259 };

struct LedPwmOutput
{
    uint16_t Red;
    uint16_t Green;
    uint16_t Blue;
};

struct FlashingLed
{
    uint8_t positionX;
    uint8_t positionY;
    struct Colour alternateColour;
};

struct PulsingLed
{
    uint8_t positionX;
    uint8_t positionY;
};

struct GridLed
{
    struct Colour colour;
    enum LedLightingType ledLightingType; // light?flash?pulse
};

void grid_initializeBaseInterruptTimer();
void grid_initializeGpio();
void grid_initializePwmOutputs();
void grid_startTimers();

#endif /* GRID_BUTTONS_GRID_BUTTONS_INIT_H_ */

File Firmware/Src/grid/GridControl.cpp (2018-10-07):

#include "grid/GridControl.h"
#include "stm32f4xx_hal.h"

namespace grid
{

static const uint8_t kTimerFrameOffset = 1;

static const uint32_t kBaseInterruptClockPrescaler = 1;
static const uint32_t kBaseInterruptClockPeriod = 48000; // 500us
static const uint32_t kPwmClockPrescaler = 1;
static const uint16_t kPwmClockPeriod = 47000; // <500us - has to be shorter than base period

static const uint16_t kGridButtonMask = 0x000F;
static const uint16_t kNonGridButtonMask[2] = {0x2000, 0x0400};
static const uint16_t kRotaryEncoderMask[2] = {0xC000, 0x1800};
static const uint16_t kRotaryEncoderBitShift[2] = {14, 11};

static const uint8_t kNumberOfLedColourIntensityLevels = 65;

static GPIO_TypeDef* const GRID_BUTTON_IN_GPIO_PORT = GPIOC;
static const uint16_t BUTTON_IN1_Pin = GPIO_PIN_13;
static const uint16_t BUTTON_IN2_Pin = GPIO_PIN_10;
static const uint16_t ROTARY1_A_Pin = GPIO_PIN_14;
static const uint16_t ROTARY1_B_Pin = GPIO_PIN_15;
static const uint16_t ROTARY2_A_Pin = GPIO_PIN_11;
static const uint16_t ROTARY2_B_Pin = GPIO_PIN_12;
static const uint16_t GRID_BUTTON_IN1_Pin = GPIO_PIN_0;
static const uint16_t GRID_BUTTON_IN2_Pin = GPIO_PIN_1;
static const uint16_t GRID_BUTTON_IN3_Pin = GPIO_PIN_2;
static const uint16_t GRID_BUTTON_IN4_Pin = GPIO_PIN_3;

static GPIO_TypeDef* const verticalSegmentControlGpioPort = GPIOA;
static const uint16_t COLUMN_OUT1_Pin = GPIO_PIN_8;
static const uint16_t COLUMN_OUT2_Pin = GPIO_PIN_9;
static const uint16_t COLUMN_OUT3_Pin = GPIO_PIN_10;
static const uint16_t COLUMN_OUT4_Pin = GPIO_PIN_5;
static const uint16_t COLUMN_OUT5_Pin = GPIO_PIN_4;
static const uint16_t COLUMN_OUT6_Pin = GPIO_PIN_15;

static GPIO_TypeDef* const PWM_RED_GPIO_PORT = GPIOA;
static const uint16_t PWM_RED1_Pin = GPIO_PIN_0;
static const uint16_t PWM_RED2_Pin = GPIO_PIN_1;
static const uint16_t PWM_RED3_Pin = GPIO_PIN_2;
static const uint16_t PWM_RED4_Pin = GPIO_PIN_3;

static GPIO_TypeDef* const PWM_GREEN_GPIO_PORT = GPIOB;
const uint16_t PWM_GREEN1_Pin = GPIO_PIN_6;
const uint16_t PWM_GREEN2_Pin = GPIO_PIN_7;
const uint16_t PWM_GREEN3_Pin = GPIO_PIN_8;
const uint16_t PWM_GREEN4_Pin = GPIO_PIN_9;

static GPIO_TypeDef* const PWM_BLUE1_2_GPIO_PORT = GPIOA;
static const uint16_t PWM_BLUE1_Pin = GPIO_PIN_6;
static const uint16_t PWM_BLUE2_Pin = GPIO_PIN_7;
static GPIO_TypeDef* const PWM_BLUE3_4_GPIO_PORT = GPIOB;
static const uint16_t PWM_BLUE3_Pin = GPIO_PIN_0;
static const uint16_t PWM_BLUE4_Pin = GPIO_PIN_1;

static TIM_TypeDef* const PWM_TIMER_RED = TIM2;
static TIM_TypeDef* const PWM_TIMER_GREEN = TIM4;
static TIM_TypeDef* const PWM_TIMER_BLUE = TIM3;
static TIM_TypeDef* const BASE_INTERRUPT_TIMER = TIM1;

static const uint16_t BRIGHTNESS_THROUGH_PAD[kNumberOfLedColourIntensityLevels] = {
        0, 338, 635, 943, 1273, 1627, 2001, 2393,
        2805, 3237, 3683, 4149, 4627, 5121, 5641, 6157,
        6713, 7259, 7823, 8400, 9007, 9603, 10229, 10856,
        11501, 12149, 12815, 13499, 14204, 14892, 15571, 16279,
        17027, 17769, 18506, 19267, 20048, 20844, 21617, 22436,
        23219, 24066, 24897, 25725, 26599, 27430, 28301, 29198,
        30041, 30947, 31835, 32790, 33683, 34601, 35567, 36579,
        37515, 38478, 39415, 40403, 41358, 42373, 43359, 44409, 46000 };
//        0, 338, 341, 349, 363, 384, 414, 453,
//        503, 566, 641, 730, 834, 954, 1091, 1245,
//        1418, 1611, 1823, 2057, 2312, 2591, 2892, 3218,
//        3569, 3945, 4348, 4779, 5237, 5724, 6240, 6787,
//        7364, 7973, 8614, 9288, 9995, 10737, 11513, 12325,
//        13173, 14058, 14981, 15941, 16941, 17979, 19058, 20177,
//        21338, 22540, 23785, 25072, 26404, 27779, 29200, 30666,
//        32178, 33737, 35342, 36996, 38698, 40449, 42249, 44099, 46000 };

static const uint16_t BRIGHTNESS_DIRECT[kNumberOfLedColourIntensityLevels] = {
        0, 223, 308, 397, 494, 598, 709, 825,
        947, 1075, 1208, 1348, 1491, 1639, 1793, 1950,
        2113, 2279, 2448, 2621, 2802, 2981, 3164, 3354,
        3542, 3738, 3931, 4133, 4337, 4542, 4748, 4952,
        5166, 5382, 5591, 5809, 6032, 6259, 6473, 6699,
        6922, 7155, 7385, 7607, 7856, 8079, 8319, 8551,
        8783, 9021, 9265, 9500, 9753, 9995, 10233, 10489,
        10737, 10989, 11213, 11489, 11729, 11987, 12203, 12480, 12741 };

static const uint32_t kColumnSelectValue[GridControl::numberOfVerticalSegments] = {
        0xF8DF, 0xF9DF, 0xFADF, 0xFBDF,
        0xFCDF, 0xFDDF, 0xFEDF, 0xFFDF,
        0x78FF, 0x7AFF, 0xF8EF, 0xF9EF,
        0xFAEF, 0xFBEF, 0xFCEF, 0xFDEF,
        0xFEEF, 0xFFEF, 0x79FF, 0x7BFF };

uint8_t GridControl::currentlyStableInputBufferIndex_ = 1;
bool GridControl::gridInputUpdated_ = false;
bool GridControl::switchInputUpdated_ = false;

uint32_t GridControl::buttonInput_[nNumberOfButtonDebouncingCycles][numberOfVerticalSegments];
uint32_t GridControl::pwmOutputRed_[numberOfVerticalSegments][numberOfHorizontalSegments];
uint32_t GridControl::pwmOutputGreen_[numberOfVerticalSegments][numberOfHorizontalSegments];
uint32_t GridControl::pwmOutputBlue_[numberOfVerticalSegments][numberOfHorizontalSegments];

static TIM_HandleTypeDef pwmTimerRed;
static TIM_HandleTypeDef pwmTimerGreen;
static TIM_HandleTypeDef pwmTimerBlue;
static TIM_HandleTypeDef baseInterruptTimer;
static DMA_HandleTypeDef buttonInputDmaConfiguration;
static DMA_HandleTypeDef pwmOutputRedDmaConfiguration;
static DMA_HandleTypeDef pwmOutputGreenDmaConfiguration;
static DMA_HandleTypeDef pwmOutputBlueDmaConfiguration;
static DMA_HandleTypeDef columnSelectDmaConfiguration;


extern "C" void DMA2_Stream5_IRQHandler()
{
    HAL_DMA_IRQHandler(&buttonInputDmaConfiguration);
}

static void inputReadoutToMemory0CompleteCallbackWrapper( __DMA_HandleTypeDef* hdma )
{
    GridControl::inputReadoutToMemory0CompleteCallback();
}

static void inputReadoutToMemory1CompleteCallbackWrapper( __DMA_HandleTypeDef* hdma )
{
    GridControl::inputReadoutToMemory1CompleteCallback();
}

static void dmaErrorCallback( __DMA_HandleTypeDef* hdma ) // unused
{
}

GridControl::GridControl()
{
    for (uint8_t segment = 0; segment < numberOfVerticalSegments; segment++)
    {
        buttonInput_[0][segment] = 0x0000;
        buttonInput_[1][segment] = 0x0000;
    }
    turnAllLedsOff();
}

GridControl::~GridControl()
{
}

bool GridControl::getButtonInput( const uint8_t button ) const
{
    return (0 != (kNonGridButtonMask[button] & buttonInput_[currentlyStableInputBufferIndex_][0]));
}

uint8_t GridControl::getGridButtonInput( const uint8_t column ) const
{
    return static_cast<uint8_t>(kGridButtonMask & buttonInput_[currentlyStableInputBufferIndex_][column]);
}

uint8_t GridControl::getRotaryEncodersInput( const uint8_t encoder, const uint8_t timeStep ) const
{
    const uint8_t index = timeStep * 2;
    return (kRotaryEncoderMask[encoder] & buttonInput_[currentlyStableInputBufferIndex_][index])>>kRotaryEncoderBitShift[encoder];
}
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

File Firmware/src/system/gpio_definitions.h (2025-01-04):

#pragma once

#include "stm32f4xx_hal.h"

namespace mcu {

GPIO_TypeDef* const GRID_BUTTON_IN_GPIO_PORT = GPIOC;
const uint16_t BUTTON_IN1_Pin = GPIO_PIN_13;
const uint16_t BUTTON_IN2_Pin = GPIO_PIN_10;
const uint16_t ROTARY1_A_Pin = GPIO_PIN_14;
const uint16_t ROTARY1_B_Pin = GPIO_PIN_15;
const uint16_t ROTARY2_A_Pin = GPIO_PIN_11;
const uint16_t ROTARY2_B_Pin = GPIO_PIN_12;
const uint16_t GRID_BUTTON_IN1_Pin = GPIO_PIN_0;
const uint16_t GRID_BUTTON_IN2_Pin = GPIO_PIN_1;
const uint16_t GRID_BUTTON_IN3_Pin = GPIO_PIN_2;
const uint16_t GRID_BUTTON_IN4_Pin = GPIO_PIN_3;

GPIO_TypeDef* const COLUMN_OUT_GPIO_PORT = GPIOA;
const uint16_t COLUMN_OUT1_Pin = GPIO_PIN_8;
const uint16_t COLUMN_OUT2_Pin = GPIO_PIN_9;
const uint16_t COLUMN_OUT3_Pin = GPIO_PIN_10;
const uint16_t COLUMN_OUT4_Pin = GPIO_PIN_5;
const uint16_t COLUMN_OUT5_Pin = GPIO_PIN_4;
const uint16_t COLUMN_OUT6_Pin = GPIO_PIN_15;

GPIO_TypeDef* const PWM_RED_GPIO_PORT = GPIOA;
const uint16_t PWM_RED1_Pin = GPIO_PIN_0;
const uint16_t PWM_RED2_Pin = GPIO_PIN_1;
const uint16_t PWM_RED3_Pin = GPIO_PIN_2;
const uint16_t PWM_RED4_Pin = GPIO_PIN_3;

GPIO_TypeDef* const PWM_GREEN_GPIO_PORT = GPIOB;
const uint16_t PWM_GREEN1_Pin = GPIO_PIN_6;
const uint16_t PWM_GREEN2_Pin = GPIO_PIN_7;
const uint16_t PWM_GREEN3_Pin = GPIO_PIN_8;
const uint16_t PWM_GREEN4_Pin = GPIO_PIN_9;

GPIO_TypeDef* const PWM_BLUE1_2_GPIO_PORT = GPIOA;
const uint16_t PWM_BLUE1_Pin = GPIO_PIN_6;
const uint16_t PWM_BLUE2_Pin = GPIO_PIN_7;
GPIO_TypeDef* const PWM_BLUE3_4_GPIO_PORT = GPIOB;
const uint16_t PWM_BLUE3_Pin = GPIO_PIN_0;
const uint16_t PWM_BLUE4_Pin = GPIO_PIN_1;

GPIO_TypeDef* const LCD_GPIO_Port = GPIOB;
const uint16_t RESET_Pin = GPIO_PIN_2;
const uint16_t DC_Pin = GPIO_PIN_10;
const uint16_t CS_Pin = GPIO_PIN_12;
const uint16_t SCK_Pin = GPIO_PIN_13;
const uint16_t MOSI_Pin = GPIO_PIN_15;
const uint16_t LIGHT_Pin = GPIO_PIN_5;

}  // namespace mcu

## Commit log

2018-01-04 multiple schematic and pcb changes
    [digital_io.sch, grid.sch, mcu.sch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]
2018-01-05 pcb in development
    [digital_io.sch, grid.sch, mcu.sch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]
2018-01-06 pcb development
    [midi_grid.kicad_pcb]
2018-01-07 commiting before bulk led schematic symbol change
    [grid.sch, mcu.sch, midi_grid.kicad_pcb]
2018-01-07 successfuly changed component symbols and net names, further developed pcb
    [grid.sch, mcu.sch, midi_grid.kicad_pcb]
2018-01-08 added logos to pcb
    [grid.sch, mcu.sch, midi_grid.kicad_pcb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]
2018-01-09 added net names in grid schematic
    [grid.sch, midi_grid.kicad_pcb]
2018-01-10 moved files to PCB folder
    [digital_io.sch, grid.sch, mcu.sch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]
2018-01-20 deleting all the files from repo for a fresh start
    [digital_io.sch, grid.sch, mcu.sch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]
2018-01-20 adding hardware files
    [digital_io.sch, grid.sch, mcu.sch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]
2018-01-23 linked footprints with 3D models in project directory
    [digital_io.sch, grid.sch, mcu.sch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]
2018-01-24 added BOM, changed names of some components in the schematic
    [BOM.ods, grid.sch, midi_grid.kicad_pcb]
2018-01-24 added image of PCB 3D render
2018-01-25 copied project cache library to project_library.lib
    [BOM.ods, grid.sch]
2018-01-25 added CubeMX project, re-generated a PDF schematic
2018-01-27 updated CubeMX project and BOM
    [BOM.ods]
2018-01-27 changed pin of LCD CS, so hardware chip select could be used
    [digital_io.sch, grid.sch, mcu.sch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]
2018-01-31 managed to run program on device, added debugger configuration file
    [midi-grid Debug.cfg]
2018-02-01 wrote PWM timer initialization function
2018-02-02 changed LED current limiting resistor values
    [BOM.ods, grid.sch, midi_grid.kicad_pcb]
2018-02-03 managed to light some leds
2018-02-04 adopted almost all functions from the prototype, leds can be set using midi messages
2018-02-06 stabilized led switching, program works for color testing now
    [grid_buttons.c, grid_buttons_configuration.c, grid_buttons_configuration.h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]
2018-02-07 leds and buttons are working
2018-02-09 added brightness measurement function, it does not work yet
    [grid_buttons.c, main.c]
2018-02-10 changed resistor values, added drum layout output
    [BOM.ods, grid.sch, midi_grid.kicad_pcb]
2018-02-25 managed to control lcd using SPI and DMA
2018-02-26 fixed pulsing led issue, added some lcd functionality
    [grid_buttons.c, main.c]
2018-03-04 managed to rework lcd functions into c++ classes
    [main.cpp]
2018-03-11 managed to enable lcd backlight pwm
2018-03-13 added midi activity functionality, although it has some nasty bug
    [Launchpad.cpp, main.cpp]
2018-03-20 changed VID/PID, expanded readme
2018-04-01 implemented timing status functionality, fixed a ring buffer issue by momentarily disabling interrupts
    [Launchpad.cpp]
2018-04-08 added Switches class, moved grid isr to inline function
2018-04-25 added 3D model of the case
2018-05-09 added reset to bootloader functionality, device can now be updated through USB using ST's Dfuse tool
    [main.cpp]
2018-05-27 replaced interrupt based grid implementation with DMA driven implementation
    [GridControl.cpp, GridControl.h, main.cpp]
2018-06-04 fixed some of the classes cosmetically
    [Launchpad.cpp]
2018-06-06 made cosmetic changes for most of the classes, reverted LcdControl class files to working revision
    [GridControl.cpp, GridControl.h, Launchpad.cpp]
2018-06-06 fixed some style issues in LcdControl class
    [GridControl.cpp, main.cpp]
2018-06-09 implemented backlight intensity control using SPI
2018-06-10 moved lcd backlight's stuff to separate class, fixed compiler warnings in HAL
    [GridControl.cpp, GridControl.h, Launchpad.cpp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]
2018-06-11 rerouted LCD_LIGHT pin to PB5
    [mcu.sch, midi_grid.kicad_pcb, midi_grid.sch]
2018-06-18 reconfigured PWM channels to operate with more human readable output values
2018-07-01 expanded/edited readme files
    [midi_grid.kicad_pcb]
2018-09-13 replaced names 'row' and 'column' into more distinguishable ones for grid control, changed configuration to run on Linux
    [GridControl.cpp, GridControl.h, Launchpad.cpp]
2018-10-02 made all HAL *InitTypeDef structures static, which fixed all strange issues for now. Improved architecture
    [GridControl.cpp, main.cpp]
2018-10-04 removed hal from almost all class header files, added global interrupts class
2018-10-09 replaced 'colour' with 'color' globally
    [GridDriver.cpp, GridDriver.h, Launchpad.cpp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]
2018-10-16 refactored magic numbers in Launchpad class, fixed operation before midi is received
    [Launchpad.cpp, main.cpp]
2019-03-14 implemented FreeRTOS scheduler into project
    [midi-grid Debug.cfg]
2019-03-16 replaced refresh led calls with FreeRTOS timer classes
    [Launchpad.cpp, main.cpp]
2019-03-21 replaces FreeRTOStimers with threads, made Lcd class into a thread
    [Launchpad.cpp]
2019-03-25 added mechanical parts to BOM
    [BOM.ods]
2019-03-26 moved internal menu into separate class, consisting of thread handlers - FURURE
2019-04-08 replaced queue32 implementation with freertos queue, fixed additional button delay bug
    [GridDriver.cpp, Launchpad.cpp, System.cpp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]
2019-04-16 replaced multiple arguments with one in grid class
    [Launchpad.cpp, main.cpp]
2019-06-04 found a nasty mistake, now at least something works
    [Launchpad.cpp]
2019-06-09 it finaly works, with some minor issues
    [Launchpad.cpp]
2019-06-15 set thread priorities right
2019-06-30 moved files and namespaces, fixed most of the known issues
    [GridDriver.cpp]
2019-11-21 converted ButtonAction into enum class
2019-11-23 replaced freertos include quotation marks with angle brackets
2019-12-05 fixed pulsing LED bug
2019-12-18 enabled exceptions, fixed mock for Thread class along with PulsingLedsTest
2019-12-22 replaced '{}' with 'default' in destructors and constructors, made some tweaks to coverage reports
    [GridDriver.cpp]
2019-12-24 removed infinite loops from Thread::Run() methods, added mechanism to call private thread methods in unit tests
2019-12-24 added queue mock and unfinished grid button input test
2019-12-28 Split backlight into hardware and thread implementations
2020-01-01 moved lcd output buffer specifics to driver file, made changes to lcd file structure
2020-01-10 set up llvm to compile the firmware, fixed places, which some of errors and warnings, spotted by clang
    [Snake.cpp]
2020-01-12 updated GNU ARM tools to newest version, fixed linker warnings
2020-02-02 took care of seemingly all modernize-avoid-c-arrays warnings
    [Snake.cpp, main.cpp]
2020-02-07 replaced some c-style arrays with etl ones
    [Launchpad.cpp, main.cpp]
2020-02-07 added gerber files for hardware version v1.1
    [midi_grid-B_Cu.gbl, midi_grid-B_Mask.gbs, midi_grid-B_SilkS.gbo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]
2020-02-23 added grid button testing interface
2020-03-07 bunch of different changes as an unsuccessful attempt to fix bug in the Launchpad application
    [Launchpad.cpp, main.cpp]
2020-03-30 implemented a primitive log, fixed a bug in lcd clearArea method
    [main.cpp]
2020-04-01 implemented midi transmission/button press capture test
2020-04-04 got rid of startup and drivers folders by taking their content from submodules
2020-04-07 changed parameter type of print methods
2020-04-08 fixed log storage, and added an UT for it
    [Launchpad.cpp]
2020-04-19 replaced resistor and capacitor models
    [midi_grid.kicad_pcb]
2020-04-19 replaced model of encoder
    [midi_grid.kicad_pcb]
2020-04-20 converted all components except big tactile switches
    [digital_io.sch, grid.sch, mcu.sch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]
2020-04-21 replaced all models with .step, deleted .wrl models
    [adafruit_round_button_cap_1009.stl, digital_io.sch, grid.sch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]
2020-05-22 made arcs to work good enough for rotary encoder info
2020-06-04 renamed Image class to ImageMono, replaced microcontroller with STM32F413RH
    [BOM.ods, digital_io.sch, grid.sch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]
2020-08-15 implemented clip and track views with colors matching ones in Ableton
2020-09-17 commiting before branch switch
2020-09-20 added files of LCD module PCB
    [lcd_board-B_Cu.gbl, lcd_board-B_Mask.gbs, lcd_board-B_SilkS.gbo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]
2021-04-22 commiting hanging changes, dont even remember what they are
    [lcd_board-B_Cu.gbl, lcd_board-B_Mask.gbs, lcd_board-B_SilkS.gbo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]
